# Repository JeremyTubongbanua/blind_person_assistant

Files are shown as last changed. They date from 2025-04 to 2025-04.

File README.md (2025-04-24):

# blind_person_assistant

Design and Development of Blind Person Assistant

1st place Capstone Project within the Electrical and Software Engineering program at Ontario Tech University.

## Table of Contents

- [blind_person_assistant](#blind-person-assistant)
  - [Table of Contents](#table-of-contents)
  - [Team Members](#team-members)
  - [YouTube Video](#youtube-video)
  - [Capstone Poster](#capstone-poster)
  - [Directory Overview](#directory-overview)
  - [Overall System Architecture](#overall-system-architecture)
  - [Hardware Architecture](#hardware-architecture)
    - [Headset](#headset)
    - [Exploded System Gateway](#exploded-system-gateway)
    - [Exploded Smart Cane](#exploded-smart-cane)
  - [Software Architecture](#software-architecture)
    - [Headset](#headset-1)
    - [Smart Cane](#smart-cane)

## Team Members

Group 6:

- Andy Lau - 100754380
- Emily Lai - 100825007
- Jeremy Mark Tubongbanua - 100849092
- Natasha Naorem - 100845321

Capstone Supervisor: Dr. Khalid Hafeez

## YouTube Video

3 minute video showcasing the use cases and technical features of the project.

Watch the video (https://www.youtube.com/watch?v=-XyYb4GPD1U)

## Capstone Poster

This poster was printed and displayed at the exhibition on April 4, 2025.

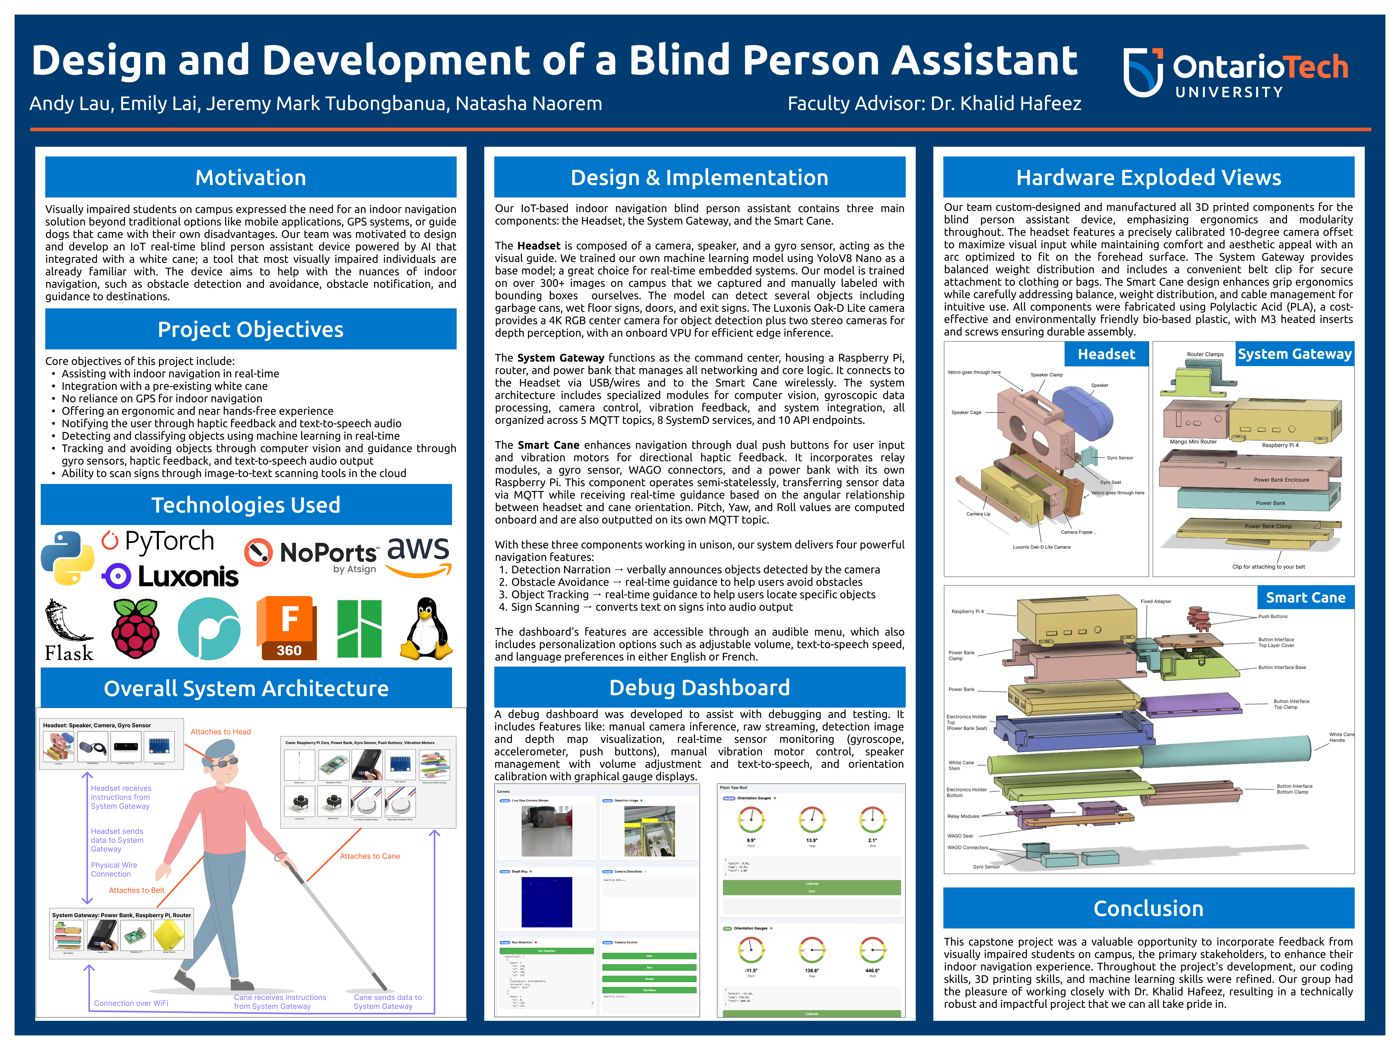
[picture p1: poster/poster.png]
Capstone Poster


Us at the exhibition:
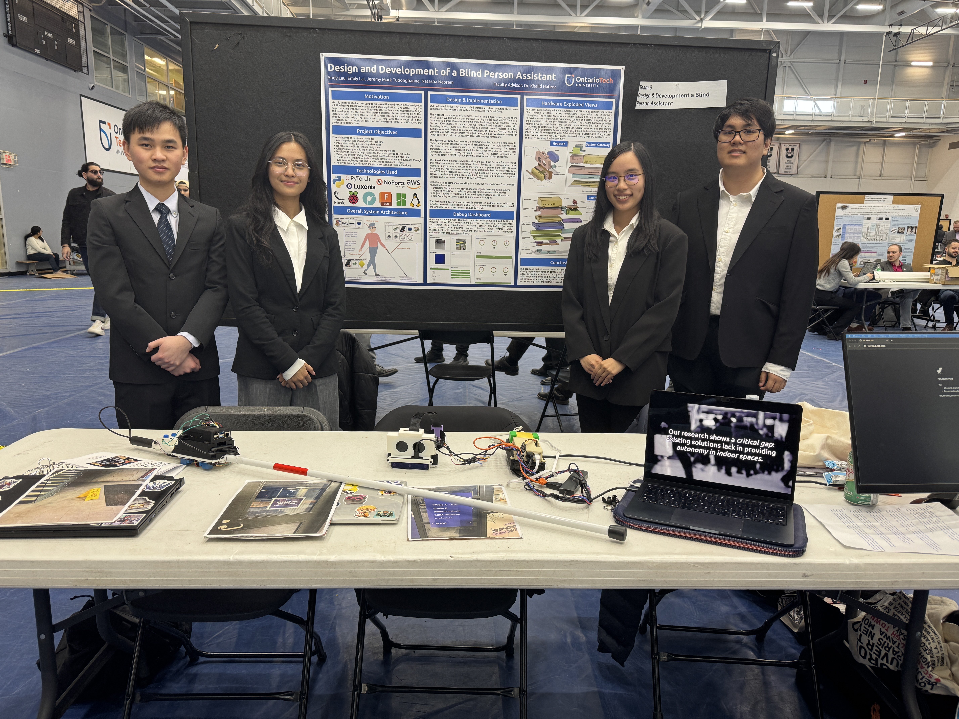
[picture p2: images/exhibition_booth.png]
Exhibition Booth


## Directory Overview

```md
blind_person_assistant/
├── model_training/ - contains YOLOv8 Nano model training code
├── headset/ - contains headset code
├── smart_cane/ - contains smart cane code
├── stls/ - contains STL files for 3D printing
├── presentations/ - contains fall and winter presentation files
├── poster/ - contains capstone poster files
├── README.md
```

## Overall System Architecture

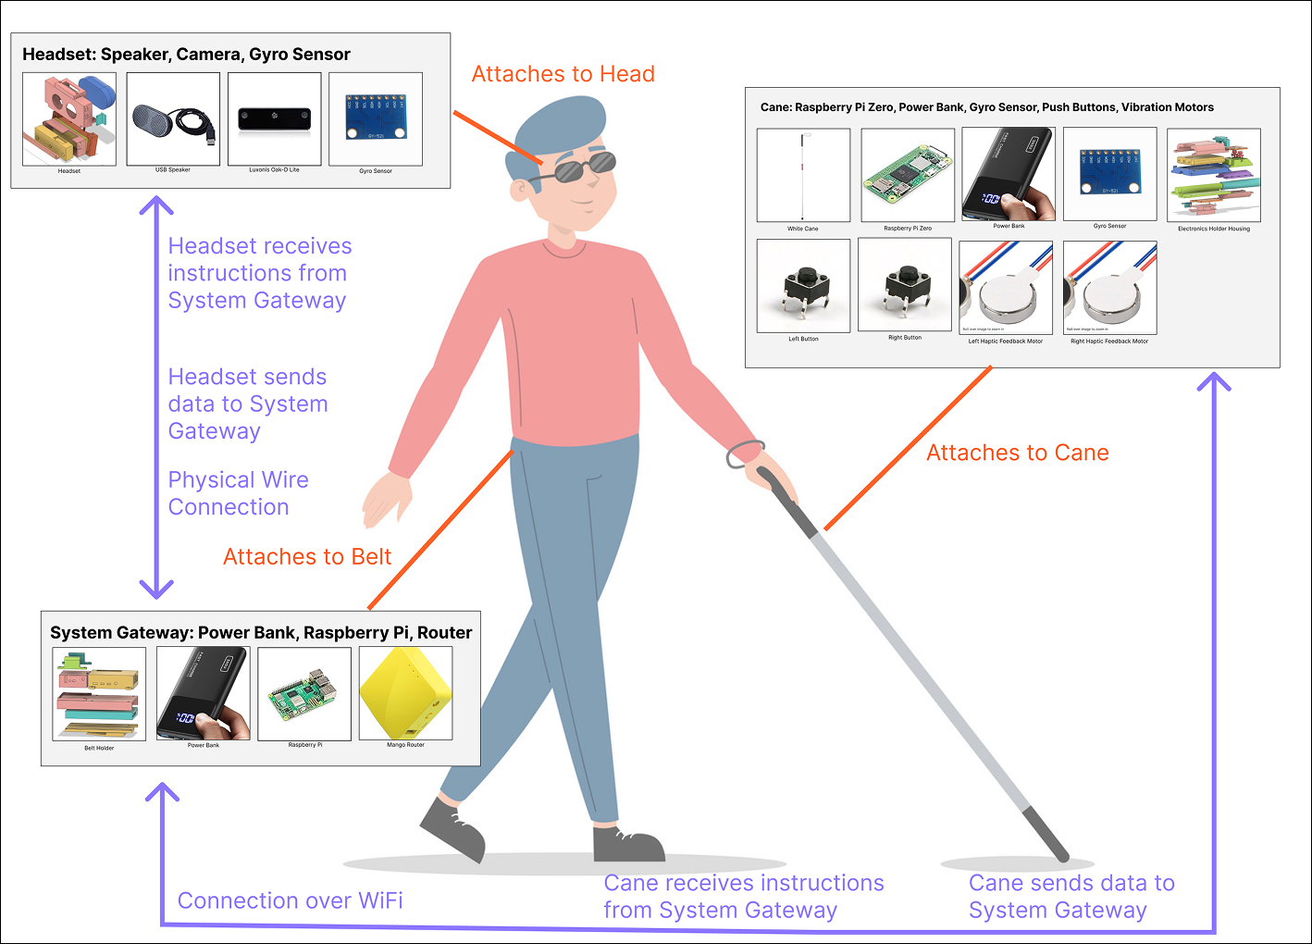
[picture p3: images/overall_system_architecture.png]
Overall System Architecture


## Hardware Architecture

We built on top of a traditional white cane (a tool that most persons who are visually impaired are familiar with) and added a few sensors to it.

### Headset

| Item | Description |
|---|---|
| Luxonis Oak-D Lite Camera | 12 MP center camera with left+right stereo cameras for depth perception |
| USB Speaker | Powered and controlled by the Pi over USB 2.0 |
| Gyro Sensor | MPU6050 |

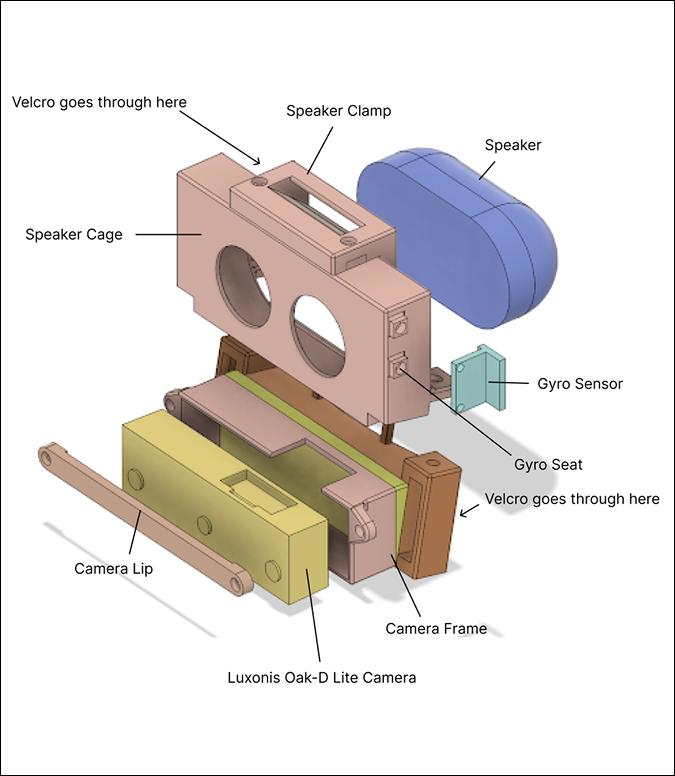
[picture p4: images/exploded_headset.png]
Exploded Headset


### Exploded System Gateway

| Item | Description |
|---|---|
| Raspberry Pi 5 | Main processing unit with 8 GB RAM, GPIO pins, and USB 3.0 ports |
| GLI Net Mango Router | Acts as access point for System Gateway Pi and Smart Cane Pi |
| Power Bank | Power delivery to the Raspberry Pi and Router |

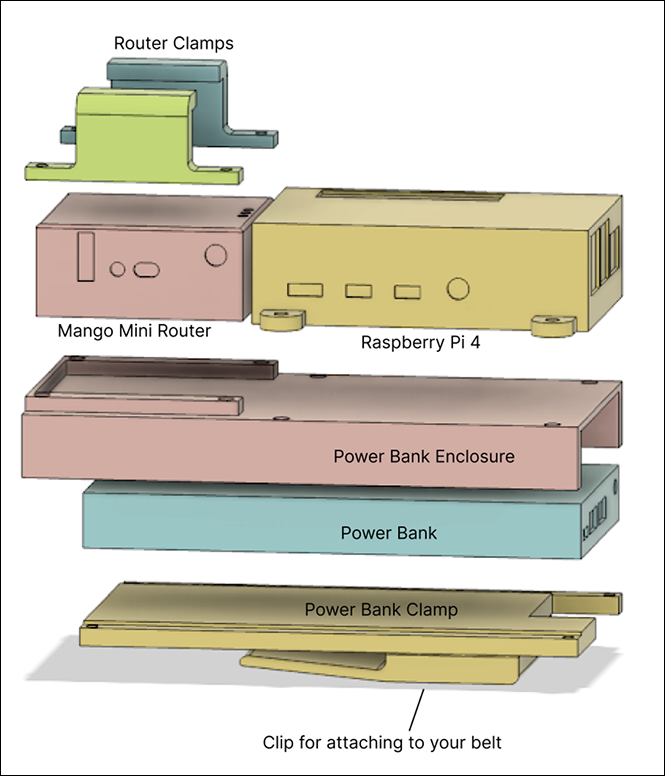
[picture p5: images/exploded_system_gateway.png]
Exploded System Gateway


### Exploded Smart Cane

| Item | Description |
|---|---|
| Raspberry Pi 4 | Main processing unit with 2 GB of RAM, GPIO pins |
| 2 Push Buttons | Connected to GND and GPIO pins |
| 2 Relay Modules | For controlling the vibration motors |
| 2 Vibration Motors | For haptic feedback |
| 2 WAGO Connectors | To act as the GND and 3.3V power rails |
| Power Bank | Power delivery to the Raspberry Pi |
| White Cane | Traditional white cane which acts as the base for the whole system |

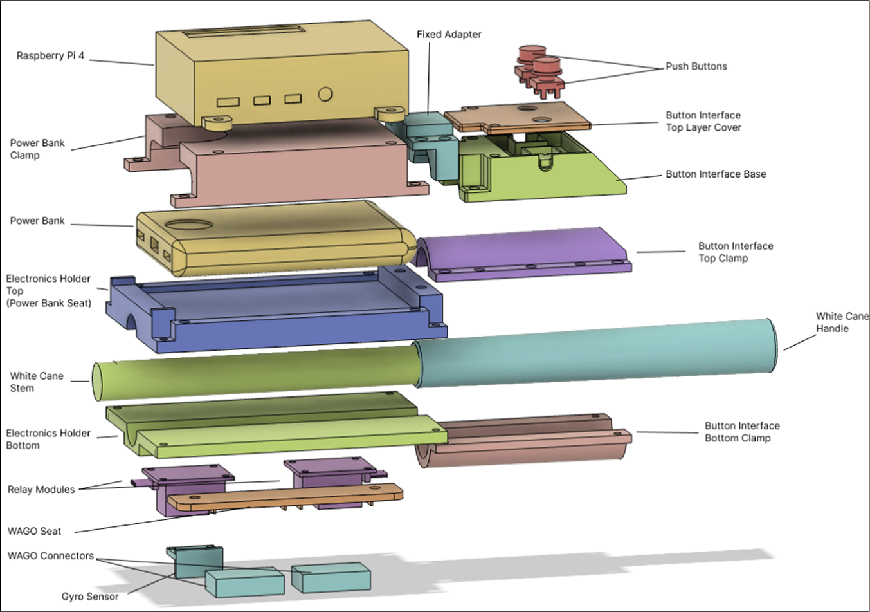
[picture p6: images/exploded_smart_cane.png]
Exploded Smart Cane


## Software Architecture

### Headset

The headset code can be found in the `headset/` directory.

| Software Module | MQTT Topic(s) | API Endpoint(s) | Description |
|---|---|---|---|
| new_camera |  1. `pi4/detections` for publishing JSON detections. 2. `pi4/depth_map` for publishing base64 depth map images for viewing purposes. 3. `pi4/detection_image` for publishing base64 detection images for viewing purposes | 1. `/video_stream` for raw live video stream. 2. `/detections` for running detections, with a comprehensive JSON reply of inference results. 3. `/` for fine tuned control of the camera | Main camera module for interfacing with the Luxonis Oak-D Lite Camera. Responsible for capturing video, calculating depth maps, running the YOLOv8 Nano model locally on the camera VPU, and outputting model inference results into MQTT topics. |
| camera_control | N/A | `/status`, `/start`, `/stop`, `/restart` | API control module for controlling the camera and getting its status. |
| speaker | N/A | 1. `/play_file` for playing preexisting audio files. 2. `/set_volume` for setting the volume of the speaker. 3. `/get_volume` for getting the volume of the speaker. 4. `/tts` for playing text-to-speech using espeak-ng lightweight TTS engine, with custom voice names, languages, and speeds. 5. `/stop` to stop audio playback. 6. `/card_info` for getting audio card information. | Audio module for interfacing with the USB speaker. Responsible for playing audio files, text-to-speech, and controlling the volume of the speaker. |
| gyro | `pi4/gyro` -> outputs raw gyro X, Y, Z, and acceleration X, Y, Z values | N/A | Stateless module for interfacing with the MPU6050 gyro sensor. Outputs raw gyro and acceleration values to the MQTT topic. |
| pitch_yaw_roll | `pi4/pitch_yaw_roll` -> outputs pitch, yaw, and roll values | 1. `/calibrate` -> runs gyro calibration sequence. 2. `/zero` zeroes the pitch, yaw, and roll values and takes the current orientation as the "zero" orientation | Stateless module for calculating the pitch, yaw, and roll of the headset using the raw gyro values. Outputs the calculated values to the MQTT topic. |
| vibration_motor_controller | `pi4/vibration_motor_controller` -> the mqtt topic that the smart cane will listen to, for vibration motor controller events sent by core | `/vibrate` -> specify left duration and right duration and the module will publish a message on controller mqtt topic. | Vibration motor controller module for controlling the vibration motors on the smart cane. Control the vibration motors using the endpoint, which publishes a message on the controller MQTT topic. |
| core | N/A | N/A | Core module for the headset. Responsible for subscribing to the MQTT topics and controlling the other modules. Runs 35 different menu options for the visually impaired user to inferace with |
| dashboard | N/A | N/A | Dashboard module for monitoring the entire system. For displaying the video stream, depth map, detection image, controlling speakers, controlling TTS engine, viewing Pitch/Yaw/Roll gauges, viewing raw sensor values and more. Mostly for exhibition purposes. |

### Smart Cane

The smart cane code can be found in the `smart_cane/` directory.

| Software Module | MQTT Topic(s) | API Endpoint(s) | Description |
|---|---|---|---|
| buttons | `pi2/button_state` | N/A | Publishes the state of the push buttons to the MQTT topic. |
| gyro | `pi2/gyro` | N/A | Stateless module for interfacing with the MPU6050 gyro sensor. Outputs raw gyro and acceleration values to the MQTT topic. |
| pitch_yaw_roll | `pi2/pitch_yaw_roll` | 1. `/calibrate` -> runs gyro calibration sequence. 2. `/zero` zeroes the pitch, yaw, and roll values and takes the current orientation as the "zero" orientation | Stateless module for calculating the pitch, yaw, and roll of the smart cane using the raw gyro values. Outputs the calculated values to the MQTT topic. |
| vibration_motors | `pi2/vibration_motor_response` | N/A | Listens to system gateway vibration motor controller, outputs response to commands on MQTT topic. Each message is paired with a uuid4. |

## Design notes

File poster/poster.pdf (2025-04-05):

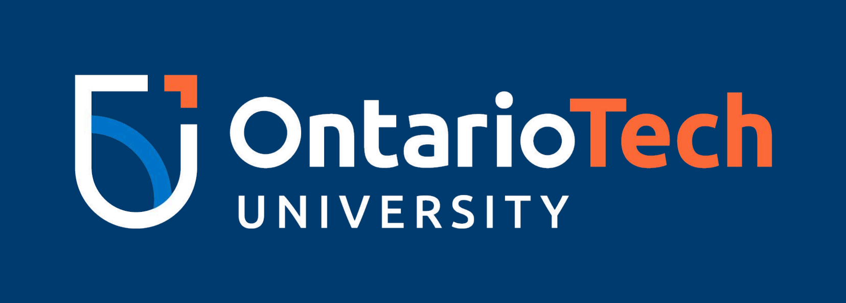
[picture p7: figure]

# Design and Development of a Blind Person Assistant

Andy Lau, Emily Lai, Jeremy Mark Tubongbanua, Natasha Naorem | Faculty Advisor: Dr. Khalid Hafeez
Motivation | Design & Implementation

# Debug Dashboard

# Project Objectives

# Hardware Exploded Views

# Conclusion

# Technologies Used

# Overall System Architecture

Visually impaired students on campus expressed the need for an indoor navigation solution beyond traditional options like mobile applications, GPS systems, or guide dogs that came with their own disadvantages. Our team was motivated to design and develop an IoT real-time blind person assistant device powered by AI that integrated with a white cane; a tool that most visually impaired individuals are already familiar with. The device aims to help with the nuances of indoor navigation, such as obstacle detection and avoidance, obstacle notification, and guidance to destinations.

Core objectives of this project includeÜ
ë Assisting with indoor navigation in real-timç
ë Integration with a pre-existing white canç
ë No reliance on GPS for indoor navigatioî
ë Offering an ergonomic and near hands-free experiencç
ë Notifying the user through haptic feedback and text-to-speech audiò
ë Detecting and classifying objects using machine learning in real-timç
ë Tracking and avoiding objects through computer vision and guidance through gyro sensors, haptic feedback, and text-to-speech audio outpu÷
ë Ability to scan signs through image-to-text scanning tools in the cloud

A debug dashboard was developed to assist with debugging and testing. It includes features like: manual camera inference, raw streaming, detection image
and | depth | map visualization, real-time | sensor | monitoring (gyroscope,
accelerometer, push buttons), manual vibration motor control, speaker management with volume adjustment and text-to-speech, and orientation calibration with graphical gauge displays.

Our IoT-based indoor navigation blind person assistant contains three main components: the Headset, the System Gateway, and the Smart Cane.

The Headset is composed of a camera, speaker, and a gyro sensor, acting as the visual guide. We trained our own machine learning model using YoloV8 Nano as a base model; a great choice for real-time embedded systems. Our model is trained on over 300+ images on campus that we captured and manually labeled with bounding boxes ourselves. The model can detect several objects including garbage cans, wet floor signs, doors, and exit signs. The Luxonis Oak-D Lite camera provides a 4K RGB center camera for object detection plus two stereo cameras for depth perception, with an onboard VPU for efficient edge inference.

The System Gateway functions as the command center, housing a Raspberry Pi, router, and power bank that manages all networking and core logic. It connects to the Headset via USB/wires and to the Smart Cane wirelessly. The system architecture includes specialized modules for computer vision, gyroscopic data processing, camera control, vibration feedback, and system integration, all organized across 5 MQTT topics, 8 SystemD services, and 10 API endpoints.

The Smart Cane enhances navigation through dual push buttons for user input and vibration motors for directional haptic feedback. It incorporates relay modules, a gyro sensor, WAGO connectors, and a power bank with its own Raspberry Pi. This component operates semi-statelessly, transferring sensor data via MQTT while receiving real-time guidance based on the angular relationship between headset and cane orientation. Pitch, Yaw, and Roll values are computed onboard and are also outputted on its own MQTT topic.

With these three components working in unison, our system delivers four powerful navigation featuresÜ
&S Detection Narration → verbally announces objects detected by the camerk
%S Obstacle Avoidance → real-time guidance to help users avoid obstacle@
KS Object Tracking → real-time guidance to help users locate specific object@
5S Sign Scanning → converts text on signs into audio output

The dashboard s features are accessible through an audible menu, which also includes personalization options such as adjustable volume, text-to-speech speed, and language preferences in either English or French.

Our team custom-designed and manufactured all 3D printed components for the blind person assistant device, emphasizing ergonomics and modularity throughout. The headset features a precisely calibrated 10-degree camera offset to maximize visual input while maintaining comfort and aesthetic appeal with an arc optimized to fit on the forehead surface. The System Gateway provides balanced weight distribution and includes a convenient belt clip for secure attachment to clothing or bags. The Smart Cane design enhances grip ergonomics while carefully addressing balance, weight distribution, and cable management for intuitive use. All components were fabricated using Polylactic Acid (PLA), a cost-effective and environmentally friendly bio-based plastic, with M3 heated inserts and screws ensuring durable assembly.

This capstone project was a valuable opportunity to incorporate feedback from visually impaired students on campus, the primary stakeholders, to enhance their indoor navigation experience. Throughout the project s development, our coding skills, 3D printing skills, and machine learning skills were refined. Our group had the pleasure of working closely with Dr. Khalid Hafeez, resulting in a technically robust and impactful project that we can all take pride in.

## Smart Cane

Headset | System Gateway

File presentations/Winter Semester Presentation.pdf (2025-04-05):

# Design and Development of a Blind Person Assistant

TEAM 6
Andy Lau
Emily Lai
Jeremy Mark Tubongbanua
Natasha Naorem

Advisor: Dr. Khalid Hafeez

1

# The Problem & Research

N

# The Problem

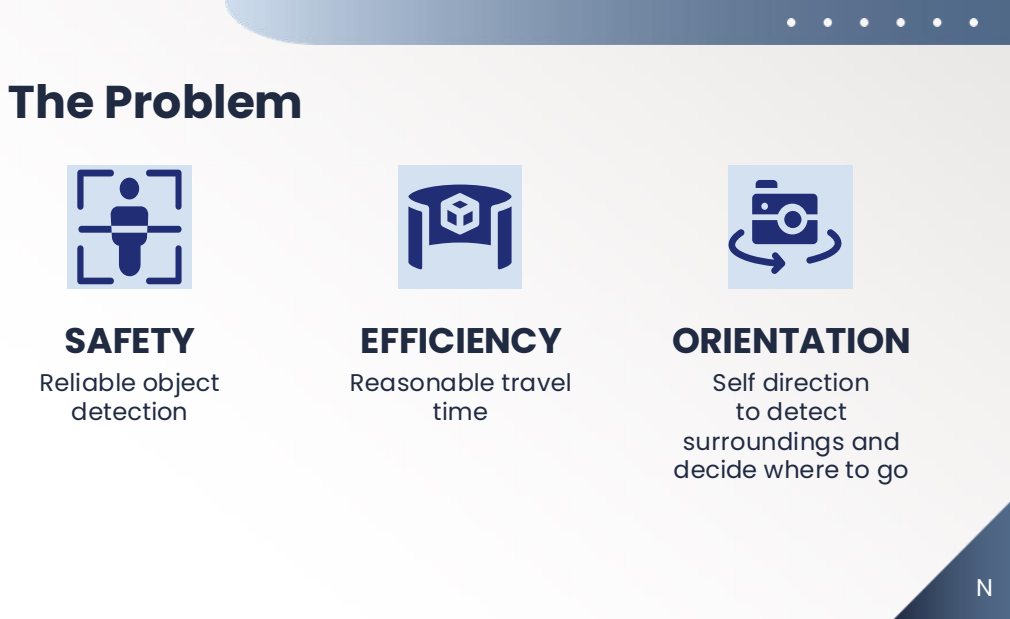
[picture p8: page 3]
SAFETY; EFFICIENCY; Reliable object detection; Reasonable travel time

ORIENTATION
Self direction
to detect
surroundings and
decide where to go

# How well do available navigation tools meet your needs?

## SURVEY QUESTION:

Compared to outdoor solutions,

# there is a gap in the market for development of suitable indoor

orientation/navigation systems.

## SURVEY CONCLUSION:

# Current indoor navigation systems do not focus on human-centered design for

visually impaired users.

## PROBLEM STATEMENT:

# Sighted Guide

# LIMITATION: Availability

N

# Current Solutions for Independent Navigation

# OBSTACLE AVOIDANCE

### Traditional Aids - White Cane - Guide Dog

### Mobile Applications - Google Maps - Lazarillo - Voice Vista

# ORIENTATION & NAVIGATION

# Stakeholder

# Discussion: Low Vision Student on Campus

### Limitation: Disruptive Navigation Simultaneous use of a white cane and mobile phone

N

# Non-Disruptive Navigation

# PROJECT OBJECTIVES

### - Increase detection range - Detect overhanging obstacles - Support the white cane

### - Reduce reliance on simultaneous use of navigation tools - Improve navigation efficiency

# Improved Obstacle Avoidance

N

2

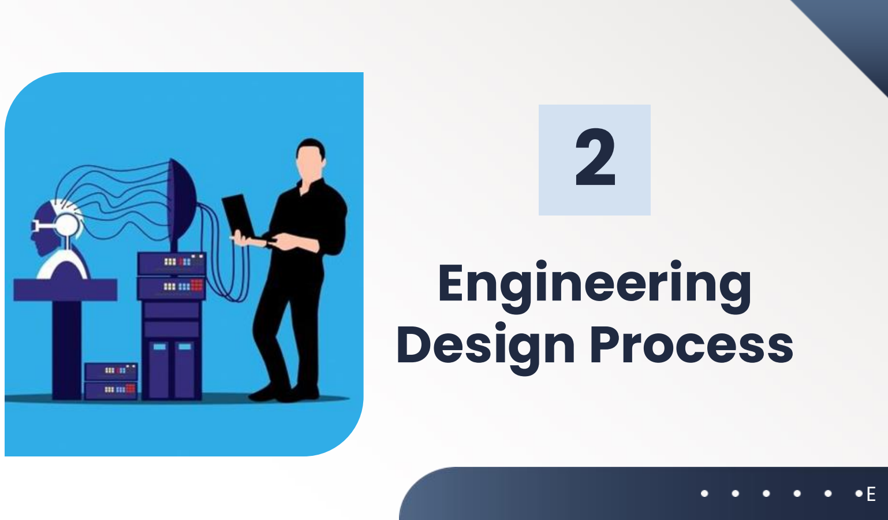
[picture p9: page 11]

# Engineering Design Process

E

# Design Requirements

When establishing a design, we wanted to meet certain requirements:

GPS is not reliant enough indoors to be used to a certain extent.

The system would need to use multiple sensors and have some way of guiding the user indoors. It would need to conduct edge computing for real-time assistance.

If we were to build an app, it can be a hassle to hold both a phone and a white cane. We want to offer a hands-free experience so that the user’s free hand can be used for better things

## Keep the White Cane

## Assist with Indoor

## Navigation in Real-Time

## Do Not Rely on a GPS

## Hands-Free Experience

Blind individuals rely heavily on their white cane, we do not want to remove or replace this crucial component.

E

# Use Cases

Detect objects in real-time, and notify the user
through TTS (text-to-speech). The user can opt
in for active detection or detection as needed.

Guide the user to an
object that was detected
and classified. The system will use sensors and
actuators to play a game
of “hot and cold” and
guide the user to a
desired object.

Many signs and poster
boards are not visually
impaired accessible. A
text scanner would help
with narrating texts, like large signs, using AWS
Textract and TTS (text-to-speech).

## Obstacle Detection &

Classification | Object Tracking | Text Scanning

Our three key features that we offer to a visually impaired user assisting with indoor navigation.

# Design Iteration 1

Smart Cane with Omni Wheel at the
Tip● | Wheel component for ease of
| cane movement
- Sensor increases range of area
| that can be sensed
Challenges ● | Wheel changes the fundamental
| white cane design
- Moving sensor may be difficult to
| track

E

# Design Iteration 2

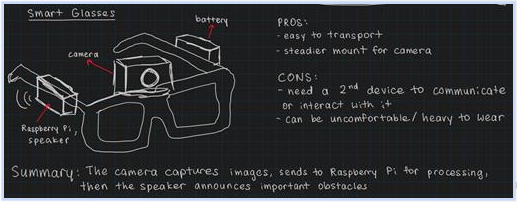
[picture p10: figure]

Smart Glasses with Camera ● | Camera captures images and
| sends to Raspberry Pi for processing
- Speaker announces important
| obstacles
Challenges ● | Poor user experience due to
| imbalanced and heavy weight on the head

E

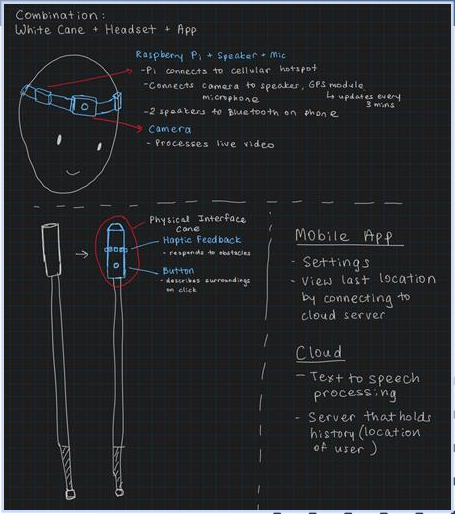
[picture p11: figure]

# Design Iteration 3

Smart Cane with Headset ● | Headset ○ | Raspberry Pi, speaker,
| | microphone, camera
- Can find obstacles and
| | report audibly to the user
- | Cane ○ | Haptic feedback for
| | obstacles
- Button for user input
- | Mobile App ○ | For settings modification

E

# The Design We

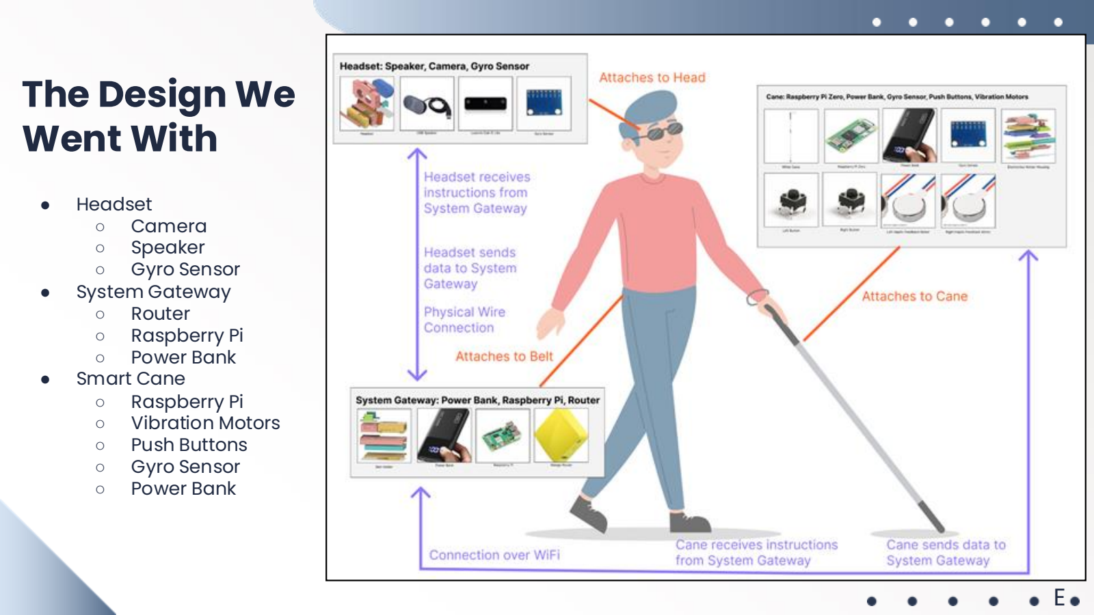
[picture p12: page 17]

Went With ● | Headset ○ | Camera ○ | Speaker ○ | Gyro Sensor ● | System Gateway ○ | Router ○ | Raspberry Pi ○ | Power Bank ● | Smart Cane ○ | Raspberry Pi ○ | Vibration Motors ○ | Push Buttons ○ | Gyro Sensor ○ | Power Bank

E

# Luxonis Oak

# -D Lite

The core piece of hardware for our capstone.
Has 3 Cameras:
1. Center

4K (12MP) RGB Camera
2. Left shutter stereo camera
3. Right shutter stereo camera Has an internal VPU (Visual Processing Unit). Edge Processing
Is Powered by USB

-C and can
transmit data through the same cable. Coding in Python and lots of documentation

E

# Depth Perception

Using the Left and Right Stereo Cameras
Mimics human binocular vision to estimate depth VPU generates a depth map
Oak-D lite comes with limitation perception range of [0.4m, 8m]

E

# Headset

Iteration 1 ● | Had a Horizontal Velcro Strap ● | Had a Camera Enclosure & Lip
Improvements Needed: ● | Needs to hold speaker ● | Needs to hold a Gyro sensor ● | USB cable is obstructive ● | Needs a vertical strap hole for

better stability on the head

J

# Headset Iteration 1.5

Never became a full iteration, but we played around with different ideas. We had trouble figuring out where to put the speaker.

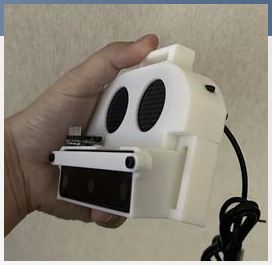
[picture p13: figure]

# Headset Iteration 2

New Features: ● | New Gyro Seat ● | New Snap-Fit Speaker Enclosure ● | Camera was flipped upside

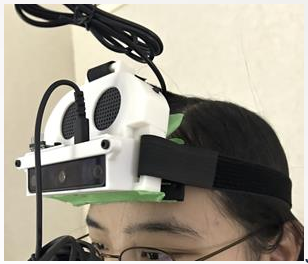
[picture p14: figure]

down to help with wire routing (which originally blocked the user’s eyes)
- Has a vertical strap hole

# Headset Iteration 3 (Final)

New Features: ● | Shifted Speaker Forward ● | More Comfortable ● | Angled Camera (more info in

next slides)

# Headset Physical Subcomponents

Put together using M3 heated inserts and M3 screws
1. Camera Frame
2. Camera Lip
3. Speaker Cage
4. Speaker Clamp
5. Gyro Seat

# Subcomponent 1:

Camera Frame ● Back of the enclosure is curved to fit

most foreheads
- Has 2 rectangular holes for a velcro strap
- Slim

-fit the Luxonis Oak

-D Lite with 0.1
mm tolerance

# Subcomponent 1: Camera Frame

Having an angled camera frame optimizes the camera view.

# Subcomponent 2: Camera Lip

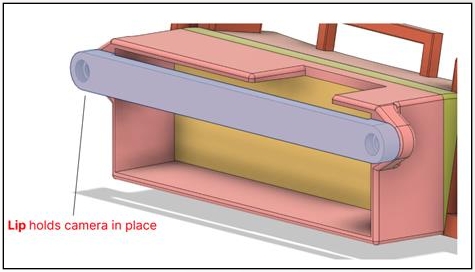
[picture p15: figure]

Lip holds the camera in place and prevents it from falling out of the enclosure, without blocking the 3 cameras.
Uses ● | 2 M3 heated inserts (on the frame) ● | 2 M3x3” screws to hold lip in place

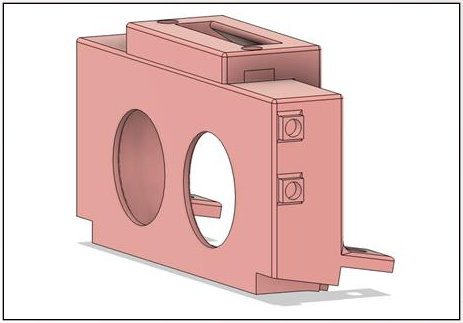
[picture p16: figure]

# Subcomponent 3: Speaker Cage

USB Speaker is snap

-fitted into the Speaker
Cage
Speaker Cage is screwed onto the Frame using M3 heated inserts and M3 screws.

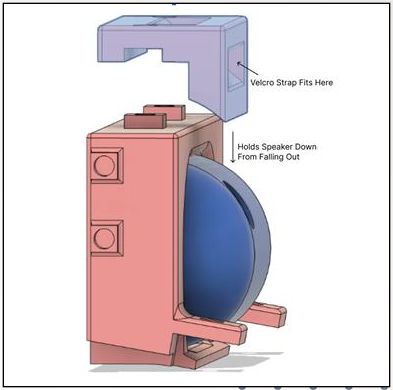
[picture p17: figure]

# Subcomponent

4:

# Speaker Clamp

Two features
1. Has a rectangular hole for a vertical velcro strap that runs on top of the head
2. Holds the speaker down from falling out of the snap

-fitted cage
Speaker clamp is held down by 2 M3 heated inserts and 2 M3 screws

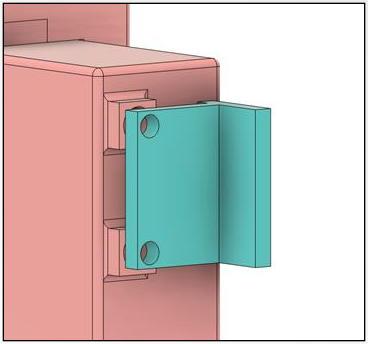
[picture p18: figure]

# Subcomponent 5: Gyro Seat

Additionally, two heated inserts are added to the Speaker Cage
The Gyro Sensor for the headset is screwed down to the Speaker Cage on its side.

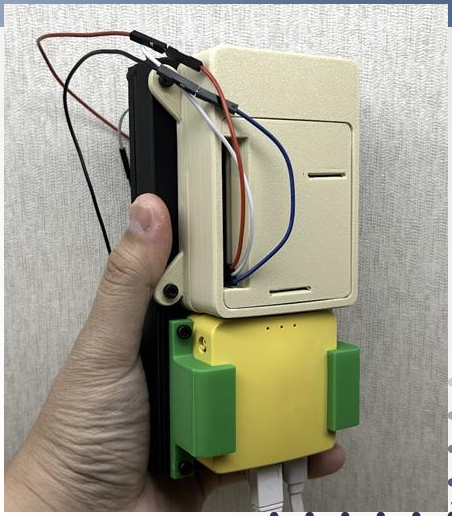
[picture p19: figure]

# System Gateway

Is physically connected to the
Headset’s components (Camera, Gyro Sensor, and USB Speaker)
Communicates with the Smart Cane Runs the core business logic and makes critical decisions
Consists of: ● | Raspberry Pi ● | Router ● | Power Bank

# System Gateway:

# Exploded View

Most items are either clamped or screwed using M3 heated inserts, screws, and nuts.
A belt clip is there in case you want to put it on your belt.

# System Gateway

# Subcomponents

Design Subcomponents:
1. Mango Router Clamps
2. Power Bank Enclosure
3. Power Bank Clamp

# System Gateway Design Subcomponent 1

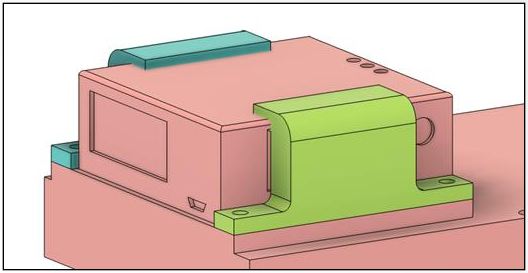
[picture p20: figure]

Holds the Router down in place
Ensures no important ports are blocked

# System Gateway Design Subcomponent 2

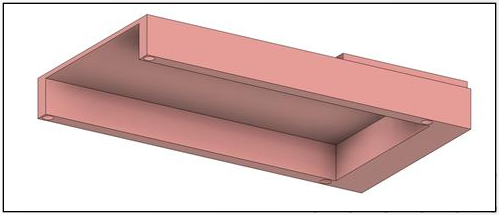
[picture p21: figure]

Power Bank Enclosure holds the power bank, with tolerance 0.1mm
Has heated inserts for various other parts to attach themselves to.

# System Gateway Design Subcomponent 3

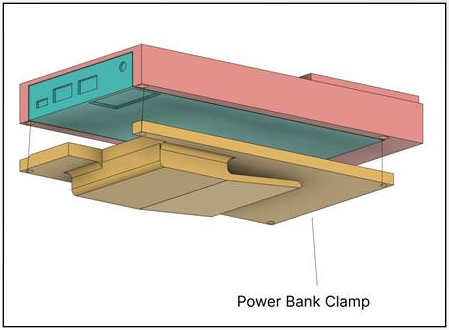
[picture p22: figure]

The Power Bank Clamp clamps the power bank to the enclosure, and offers a clip so it can be tucked away nicely on a pants, belt, or bag.

# Smart Cane

Utilizes a standard White Cane as its base.
Acts as an interface for the user to interact with the system
Contains ● | Raspberry Pi ● | Push Buttons ● | Gyro Sensor ● | Relay Modules ● | Vibration Motors ● | WAGO Terminal Connectors (5V

and GND)

# Smart Cane Iteration 1

Goods: ● | Had a Gyro Seat ● | Had a Raspberry Pi Zero holder ● | Had a Power Bank Clamp
Bad● | No Button Interface ● | Would Spin with the Cane

# Smart Cane Iteration 2

Improvements Made: ● | Added a Button Interface ● | Power Bank Clamp Hole was added so that

you can view the battery %
- The Electronics Holder component is attached to the button interface, which is fixed, so now they are both fixed and will not spin.
Future Improvements: ● | | Needs a regular Raspberry Pi to use I 2C with Gyro Sensor
- A place for Relay Modules to control the
| | Vibration Motors

# Smart Cane Iteration 3 (Final)

New Features:
- Added Relay Modules
- Added WAGO Connectors to act as terminals for 5V and GND
- Added a Raspberry Pi 4 mount on top of Power Bank Clamp

# Smart Cane Iteration 3 (Final) 360 Video

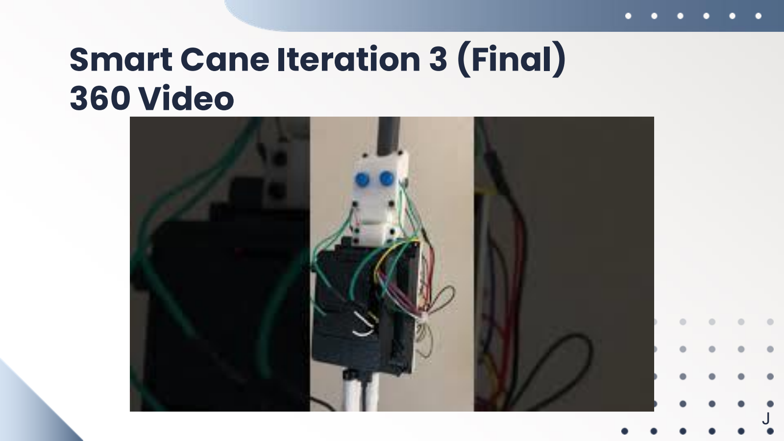
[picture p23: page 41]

Smart Cane (http://www.youtube.com/watch?v=6u8WdEg2CwE)

# Smart Cane Exploded View

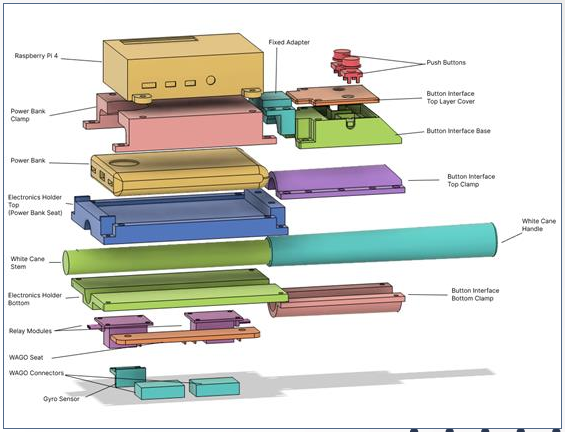
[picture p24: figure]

Parts are held together with M3 heated inserts, nuts, and screws.
3 Design Subcomponents:
1. Button Interface
2. Adapter
3. Electronics Holder

# Smart Cane Design Subcomponent 1

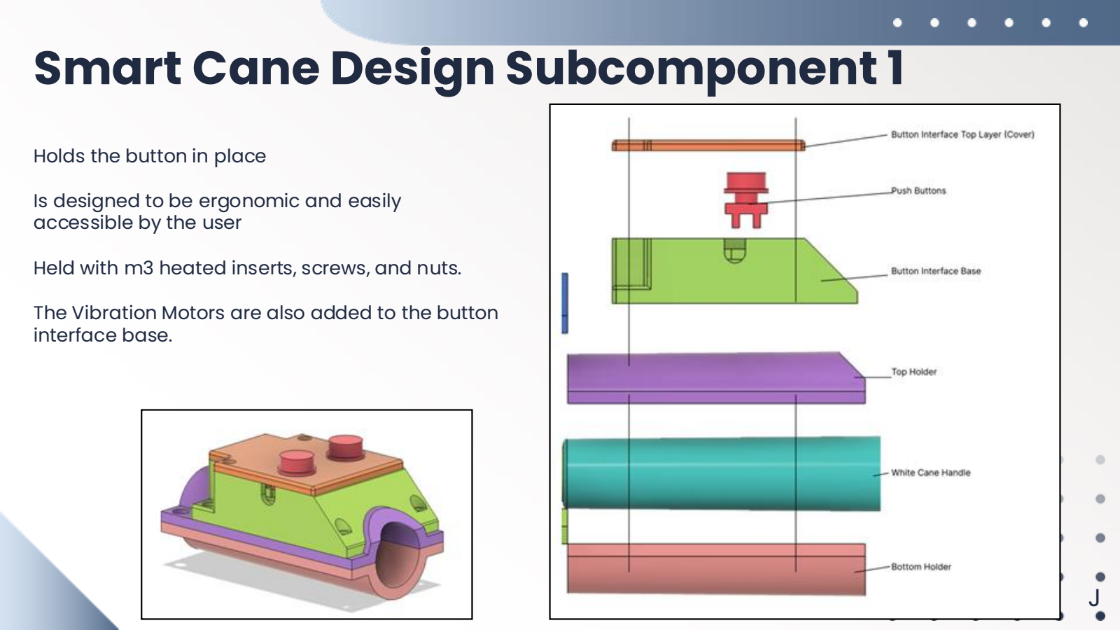
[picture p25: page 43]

Holds the button in place
Is designed to be ergonomic and easily accessible by the user
Held with m3 heated inserts, screws, and nuts. The Vibration Motors are also added to the button interface base.

# Smart Cane Design Subcomponent 2

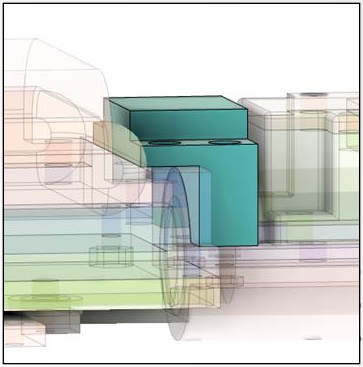
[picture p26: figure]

The adapter connects the two major subcomponents together:
1. The button interface (previous slide)
2. The electronics holder (next slide)
It ensures that the electronics holder is in a fixed position and does not spin along the white cane axis.

# Smart Cane Design Subcomponent 3

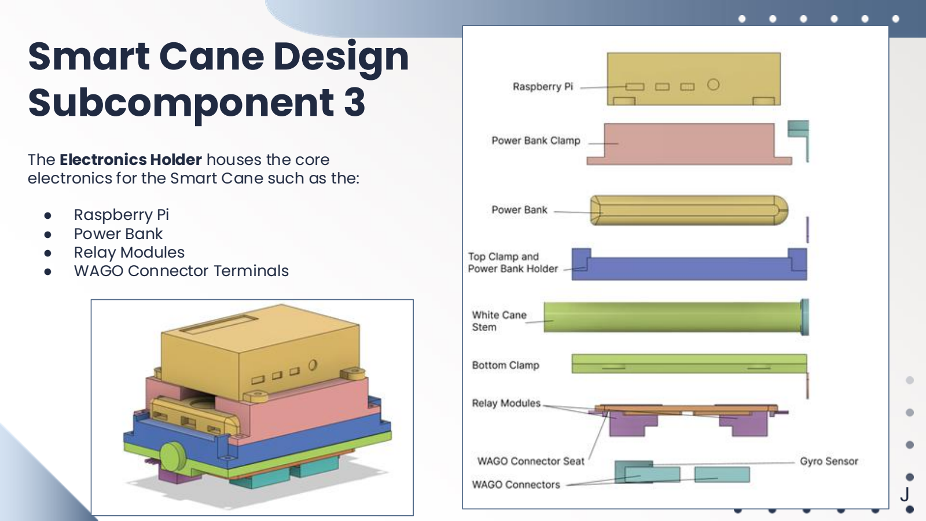
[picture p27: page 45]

The Electronics Holder houses the core electronics for the Smart Cane such as the:
- Raspberry Pi
- Power Bank
- Relay Modules
- WAGO Connector Terminals

# Smart Cane Full Assembly Screenshot 1

# Smart Cane Full Assembly Screenshot 2

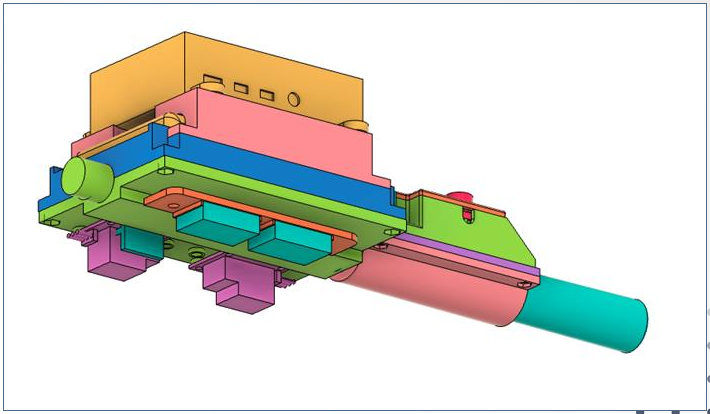
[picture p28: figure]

# Software Modules

Model Training
A jupyter notebook for training the model and converting it into a format compatible with the Luxonis Oak-D Lite

System Gateway Raspberry
Pi
Contains core business logic with critical decision making Receives Object Detections and Classifications from
Camera
Generates Depth Map
Runs daemon speaker service Contains lightweight TTS
engine
Contains daemon vibration
motor controller service
Computes Pitch, Yaw, and Roll of Headset Orientation

Smart Cane Raspberry Pi
A semi-stateless system that does two things:
1. Forwards events to the
System Gateway Pi
2. Listens for events sent from the System
Gateway Pi
Computes Pitch, Yaw, and Roll of Smart Cane Orientation

# Model Training

Collected 214 images of poles, garbage cans, doors, exit signs, general signs, wet floor signs Manually drew bounding boxes on training images
Trained using YOLOv8n as the base model
Converted to `.blob` format which is compatible with Luxonis Oak-D Lite VPU Edge Processing

E

# Model Inference Samples

Early iteration of model

E

# Model Inference Samples

Final iteration of model

E

# UA Walkthrough

capstone fall 2024 (http://www.youtube.com/watch?v=4lL-887s8Vo)

E

# System Gateway Raspberry Pi

## 8 Processes running on SystemD services

1. Camera → runs pipelines to camera, receives detections and depth map, outputs detections on MQTT

### 2. Speaker → manages volume, plays M4A files, hosts a lightweight TTS engine 3. Gyro → reads Gyro values from I2C bus and publishes on MQTT topic

4. Pitch-Yaw-Roll → computes Pitch, Yaw, and Roll from Gyro values with Gyro sensor orientation in consideration

### 5. Core → communicates with cane, runs menu options, makes critical decisions 6. Camera Controller → exposes HTTP interface to stop, start, restart, and run inference

7. Vibration Motor Controller → exposes HTTP interface to run left or right vibration motor on Smart Cane

### 8. Dashboard → exposes a HTML/CSS debug dashboard

# Smart Cane Raspberry Pi

## 4 Processes running on SystemD services

### 1. Buttons → listens for button events and publishes on MQTT topic 2. Gyro → reads Gyro values from I2C bus and publishes on MQTT topic 3. Pitch-Yaw-Roll → computes Pitch, Yaw, and Roll from gyro values and publishes to MQTT

4. Vibration Motors → listens on System Gateway MQTT and actuators vibration motors if instructed to do so.

# Debug Dashboard

15 different controls
19 different panels to view system status from Mainly used as a debug dashboard.
Contains: Gyro gauges, depth map, live video feed, speaker controls, camera controls, and manual TTS.

# Debug Dashboard

Camera Controls
- View Live Raw Camera Stream
- View the Detection Image (when detection is ran)
- View Depth Map (when detection is ran)
- View list of detections in JSON format
- Run the Detection with a button through HTTP interface
- Start, Stop, Restart the Camera or Get Camera Status

# Debug Dashboard

# Debug Dashboard

Gyro Controls ● | | | | | | Headset Raw Gyro Values (Gyro X, Y, Z,
| | | | | | Acceleration X, Y, Z)
- Smart Cane Raw Gyro Values (Gyro X, Y, Z,
| | | | | | Acceleration X, Y, Z)
- | Headset Pitch, Yaw, Roll Gauges ● | Smart Cane Pitch, Yaw, Roll, Gauges ● | Headset Calibrate Pitch, Yaw, Roll ● | Smart Cane Calibrate Pitch, Yaw, Rol, ● | Headset Zero Yaw ● | Smart Cane Zero Yaw

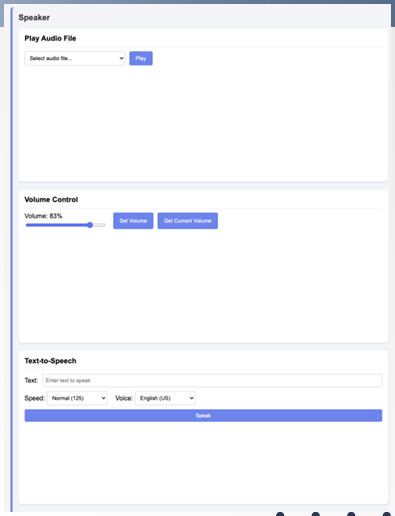
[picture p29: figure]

# Debug Dashboard

Speaker Controls
- Play a pre-downloaded audio file (like a Notification Sound)
- Set Volume (Slider)
- Get Volume
- Enter Text for the TTS Engine to Narrate
- Select Speed
- Select Voice Language/Accent

# Debug Dashboard

Button State
- View the button state MQTT topic live from the Smart Cane
- Used primarily by `core` to make effective decisions

# Debug Dashboard

Button State
- View the button state MQTT topic live from the Smart Cane
- Used primarily by `core` to make effective decisions

# Debug Dashboard

Vibration Motor Controller ● | Vibrate Motors ○ | Left for X Seconds ○ | Right for X Seconds ○ | Sends HTTP Request to Controller ● | Controller publishes a message on their

MQTT Topic on Headset Pi
- Smart Cane is listening to MQTT Topic and sends an ACK response
- Smart Cane actuates Vibration Motors through Relay Modules

# Use Case 1: Obstacle Detection & Classification

1. Camera Detects Objects
2. Speaker Service Narrates The Detections and their Distances

# Use Case 2: Object Tracking

1. Camera Detects Objects
2. Speaker Service Narrates The Detections and their Distances
3. User Chooses Which To Track
4. Gyro Sensors Calculate Angle Offset
5. Left/Right Vibration Motors Guide The User To Object

# Use Case 3: Text Scanning

1. Camera Detects a Sign
2. User Walks Up To a Sign
3. User Activates Text Scanning
4. AWS Textract is used to scan sign
5. Speaker TTS Narrates Text

3

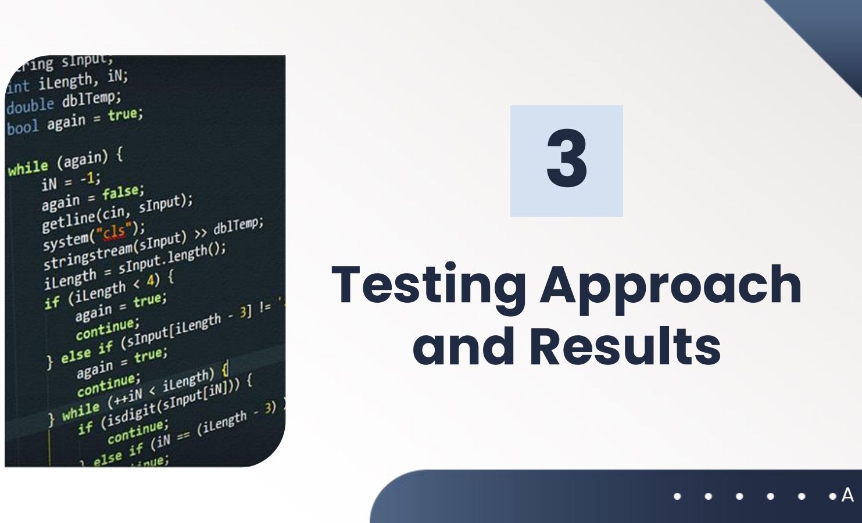
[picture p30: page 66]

# Testing Approach and Results

A

## OUR

## CRITERIA

# Testing Approach

Expectations of our tests were based on research for stakeholders and on professor’s suggestions

Our aim was to test components individually and when they were integrated together. OUR AIM

## Hardware

Hardware Components: Luxonis Oak-D Lite, Mango Router, Power Bank, Raspberry Pi 5 8 GB, Raspberry Pi 4 2 GB, USB Speaker, Push Buttons, Relay Module, Vibration Motors, Gyro Sensor
A

# Acceptance Testing Process

What We tested for:
We tested for usability, operation duration, and properly working features
Procedure
A different methodology is used for each kind of test
Manual tests are conducted when doing functional tests and results are observed by the tester
Usability tests are completed in a controlled environment, where the settings are in an indoor environment
Performance testing is tested using a testing script

# Acceptance Testing Criteria

Stakeholder Testing: The product is tested against stakeholder requirements to confirm that it meets user expectations and fulfills the intended purpose.
Functional Testing: Each system component is verified against functional specifications, ensuring that all features, workflows, and business processes operate correctly. This includes validating data processing, calculations, and system integrations.
Usability Testing: Real users interact with the system to assess its intuitiveness, accessibility, and ease of use. Feedback is gathered on learnability and user satisfaction.
Compatibility Testing: The system is tested across different browsers, operating systems, devices, and network configurations to ensure consistent performance in all intended environments. Performance Testing: The system’s responsiveness, stability, and resource utilization are evaluated under various conditions, including normal usage, peak loads, and stress scenarios. This ensures it meets performance benchmarks for speed, scalability, and reliability.

# User Scenario

User Scenarios | Related Tests
A visually impaired user is navigating through the interior of Durham College, where a support pillar is located in the center of one of the pathways. As they approach a pole, the system detects it and provides a visual bounding box with a distance estimate. | S-1
A visually impaired user is navigating through the interior of Durham College, where a support pillar is located in the center of one of the pathways. As they approach a pole, the system detects it and announces the object detected, in this case, a pole, and the distance through the headset speaker. They are also able to gauge the direction through the haptic feedback on the cane. | S-2, S-3
A system administrator opens the GUI to monitor the Smart Assistant's performance, viewing live object recognition and adjusting settings as needed. | S-4

# Stakeholder Testing

Test Case # | Test Name
S-1 | Object Recognition and Object Distance Estimation
S-2 | Text to speech functionality and speaker functionality
S-3 | Gyro Sensor Connections
S-4 | GUI for the system

These tests validate whether the system’s features function correctly in practical scenarios, and meet real word expectations of users/stakeholders

# Functional Testing

### 15 Test Cases

Functional testing ensures that each component of the Smart Assistant system operates according to the defined functional specifications. Verifies that all features, workflows, and integrations behave as expected. Most are to test software execution

Test Case # | Test Name | Description | Preconditions | Postconditions
A-1 | Announce Detections | Read detections that are inferred from the camera and use the speaker service’s Text To Speech capabilities to narrate the detections to the user | Camera is on. Objects detected. Speaker service fully functional | Detections are narrated to the user

# Usability Testing

Usability testing evaluates how intuitive and user-friendly the Smart Assistant system is for its intended audience. This process assesses ease of navigation, accessibility, and overall user experience by observing real users interacting with the interface.
Test Case # | Test Name | Description | Preconditions | Postconditions
B-1 | White Cane Button Controls Said on Speaker | Whenever a button is pressed on the white cane, the speaker will speak out what option that button does | All components of the white cane assistant are turned on | Text-to-speech command is issued to speaker
B-2 | Cane is still usable | The system is usable and intractable without the need for vision | Have the cane components physically on the cane | Able to use the cane as normal
B-3 | System is usable without vision | The system should be usable by the blind and visually impaired | Be able to interface with the system with your eyes closed | Be able to use the system

# Compatibility Testing

Make sure program is compatible with pre-existing hardware or software

Test Case # | Test Name | Description | Preconditions | Postconditions
C-1 | Dashboard on different web browsers. | Test that the debug dashboard works on different web browsers | Dashboard is operational | Dashboard is responsive and functional

# Performance Testing

Tests on if the blind person assistant system has acceptable reliability, speed, and responsiveness.

### 8 Tests

Most Tests are tested using the Test.sh script
By testing, we found the limitations of the of running the AI assistant program for too long.
Test Case # | Test Name | Description | Preconditions | Postconditions
D-1 | Headset Battery Life (Idle) | Tests the battery life capabilities under idle load | All systems and components are powered and functional in the headset, but no continuous usage. Battery is charged at 100% before test

Battery operates as
long as possible

# Test.sh


- Testing script that checks the execution time of commands
- Computes the execution time in seconds
- Ran by using connected debug laptop
- All responses are recorded in a second

## Test.S

A

# Test Results

All of all test are found to be successful Example successful cases:

Stakeholde r Test Case # | Date Test Performed | Test Owner | Result: Pass/Fail | Comments
S-1 | Object Recognition and Object Distance Estimation | Dr. Khalid Abdel Hafeez | Pass | Maybe try to make it recognize corners
Functional Test Case # | Date Test Performed | Test Owner | Result: Pass/Fail | Comments
A-1 | March 5, 2025 | Jeremy Mark Tubongbanua | Pass | Detections that are outputted by the camera stream service can be successfully narrated by the speaker using the Text To Speech engine in real-time.

# Test Results

Usability Test Case # | Date Test Performed | Test Owner | Result: Pass/Fail | Comments
B-1 | March 13, 2025 | Andy Lau | Pass | No comments
B-2 | March 13, 2025 | Jeremy Mark Tubongbanua | Pass | Typically, the visually impaired are already comfortable with a cane, so it is already integrated with a tool they are familiar with.
B-3 | March 13, 2025 | Jeremy Mark Tubongbanua | Pass | Menu navigation is functional fully with the buttons, and do not have to use your eyes in order to interact with the system

# Test Results

Compatibility
Test Case #

Date Test
Performed

Test Owner Result:
Pass/Fail

Comments

C-1 | March 13, 2025 | Jeremy Mark Tubongbanua and Emily Lai
Pass | Dashboard is
responsive
and functional
on Google
Chrome,
Safari, Firefox,
and also on
mobile
phones.

# Test Results

Performance Test Case # | Date Test Performed | Test Owner | Result: Pass/Fail | Comments
D-1 | March 13, 2025 | Jeremy Mark Tubongbanua | Pass | ~10 hour long battery life
D-2 | March 13, 2025 | Jeremy Mark Tubongbanua | Pass | ~6 hour long battery life
D-3 | March 13, 2025 | Emily Lai | Pass | ~12 hour long battery life

# Issues and Defects

Defect# | Action Item(s) | Improvement(s)
1 | During test A-1, the camera was overheating. | Improvement was implemented such that camera inference can be controlled on demand. Continuous camera inference was causing the camera to overheat, so this method was opted out of.
2 | Improper Camera Inference was common during test A-1. | Increasing the confidence threshold to 80% caused improper inferences to be less frequent.
3 | Objects weren’t being detected during test A-1. | Since the threshold was too high, the confidence threshold of the machine learning model was reduced to 60%.
4 | Vibration Motors burnt out during test D-5 | Due to an electrical issue, the vibration motors were burnt out and had to be replaced. To ensure this did not happen again, we ensured wires avoided touching each other using electrical tape.

# Budget

Total budget: $1,062.12

# Thank You

Any Questions?

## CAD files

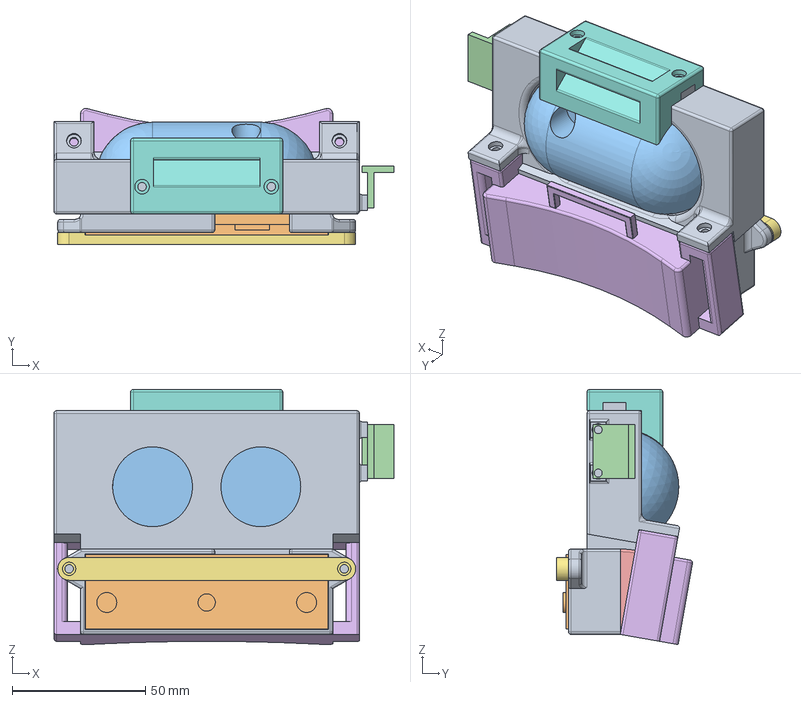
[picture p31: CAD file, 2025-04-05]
stls/Headset/HeadsetAssembly/HeadsetAssembly.step
127.8 x 51.2 x 95.9 mm
Frame
Luxonis Oak-D Lite
Speaker
Gyro Sensor
Betweener
Arc
Lip
SpeakerClamp
Offset

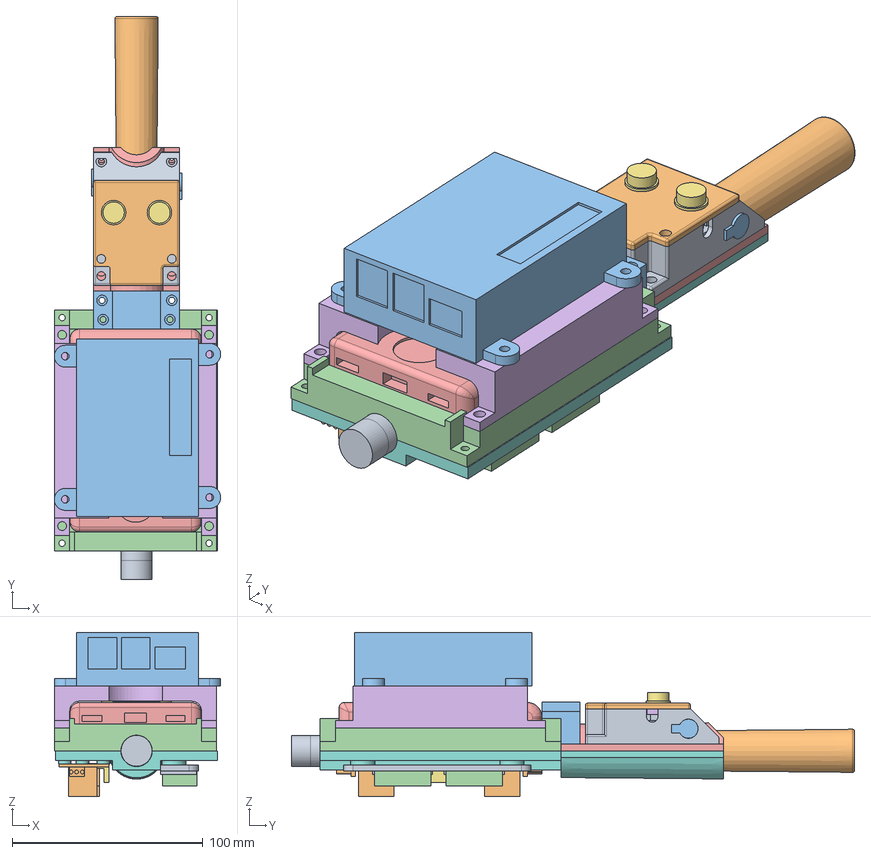
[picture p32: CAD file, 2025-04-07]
stls/SmartCane/SmartCaneAssembly/SmartCaneAssembly.step
87.2 x 295.0 x 85.9 mm
Cane Stem x 2
Cane Handle
Adapter
TopHolder
Power Bank
TopClamp
Gyro Sensor
BottomHolder
Rpi0Holder
Relay x 2
Raspberry Pi
Wago5 x 2
TopHolder_1
Button x 2
BottomHolder_1
Base
TopLayer
VibrationMotor x 2

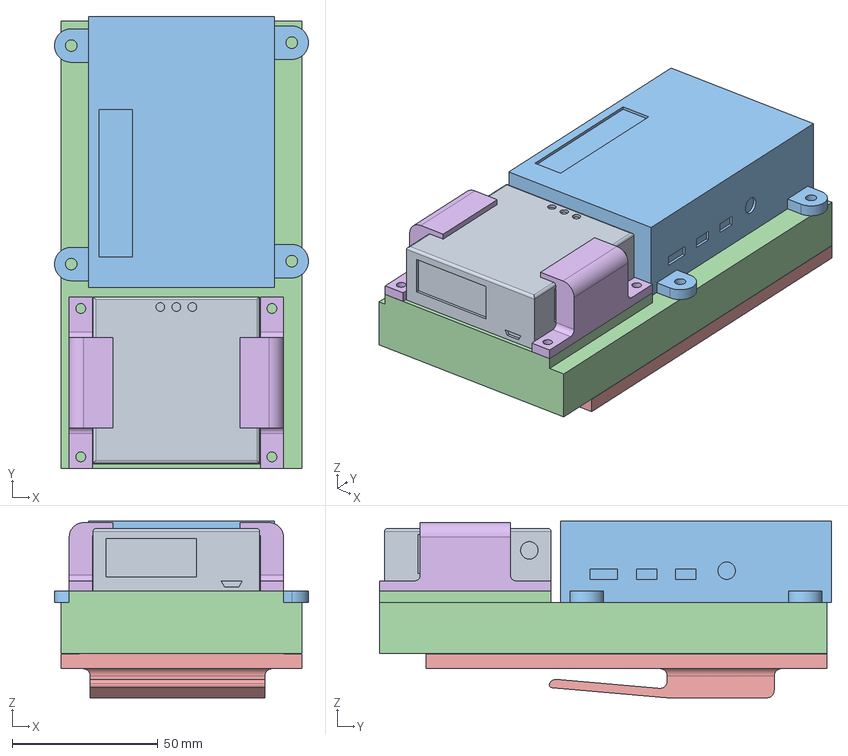
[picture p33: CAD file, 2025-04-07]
stls/SystemGateway/SystemGatewayAssembly/SystemGatewayAssembly.step
87.2 x 155.2 x 60.6 mm
Mango Router
Power Bank
Raspberry Pi
PowerBankEnclosure
PowerBankClamp
RightMangoClamp
LeftMangoClamp

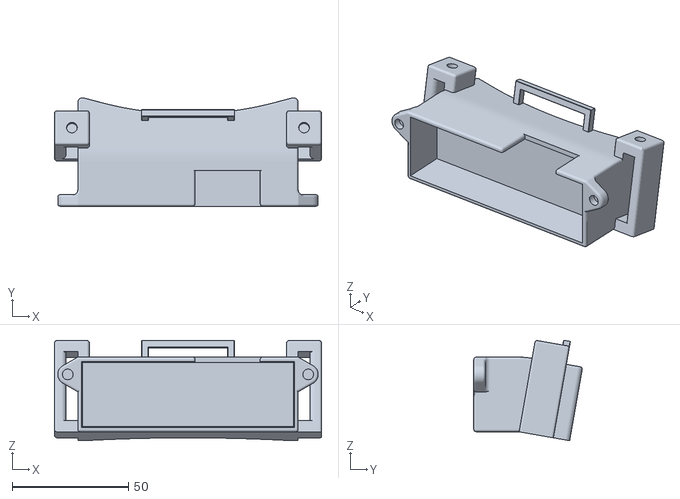
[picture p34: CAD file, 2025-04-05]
stls/Headset/HeadsetFrame/HeadsetFrameAssembly.stl
114.8 x 46.7 x 43.2

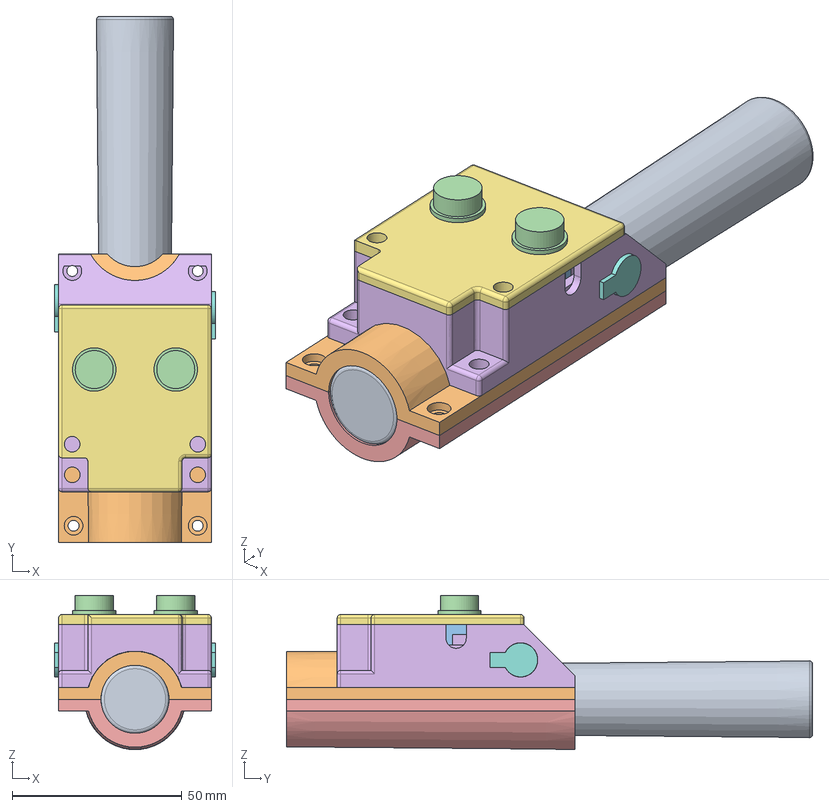
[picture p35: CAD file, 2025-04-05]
stls/SmartCane/ButtonInterface/ButtonInterfaceAssembly.step
47.4 x 155.0 x 45.4 mm
Cane Handle
TopHolder
Button x 2
BottomHolder
Base
TopLayer
VibrationMotor x 2

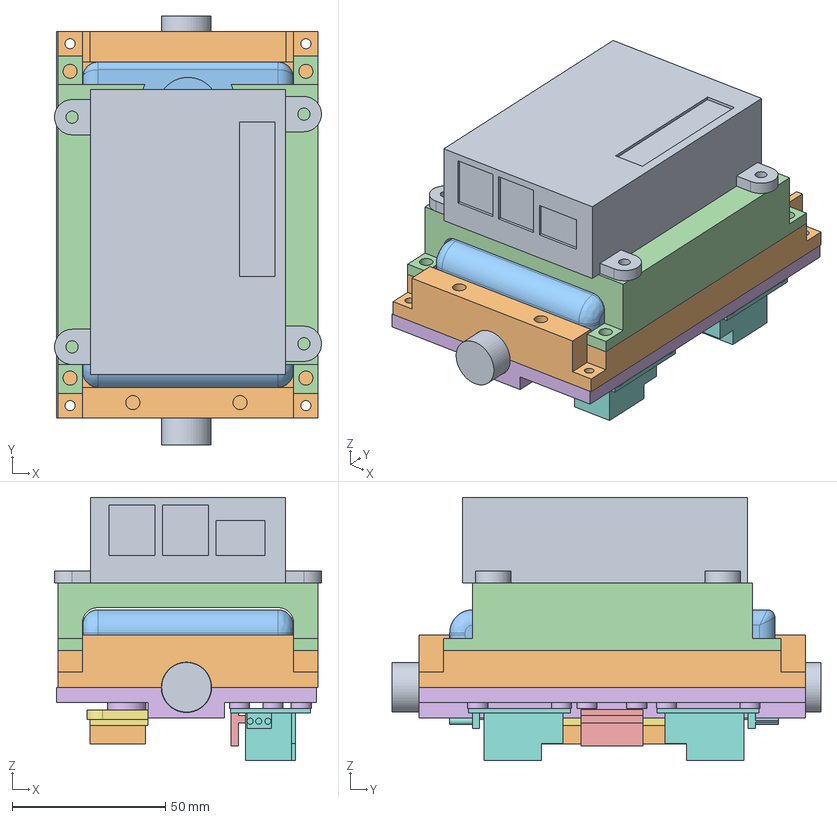
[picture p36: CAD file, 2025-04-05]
stls/SmartCane/ElectronicsHolder/ElectronicsHolderAssembly.step
87.2 x 140.0 x 85.9 mm
Cane Stem
TopHolder
Power Bank
TopClamp
Gyro Sensor
BottomHolder
Rpi0Holder
Relay x 2
Raspberry Pi
Wago5 x 2

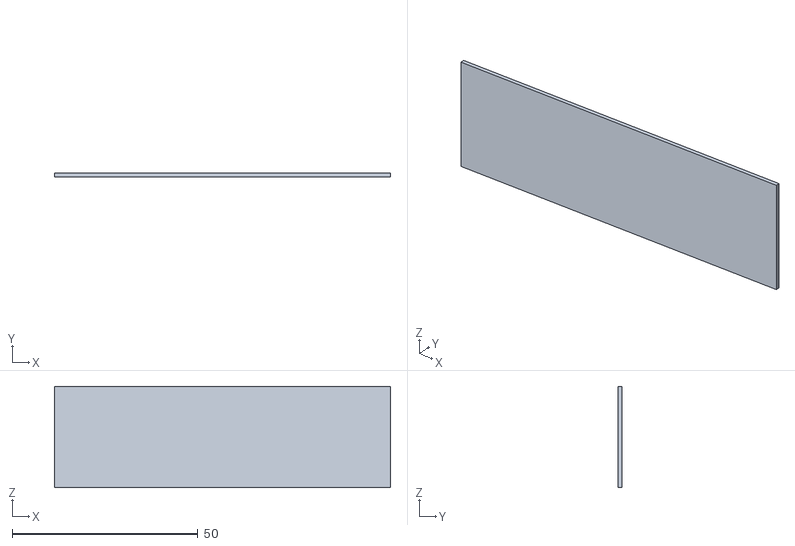
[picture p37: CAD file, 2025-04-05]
stls/Headset/CameraOffset.stl
90.4 x 1.00 x 27.2

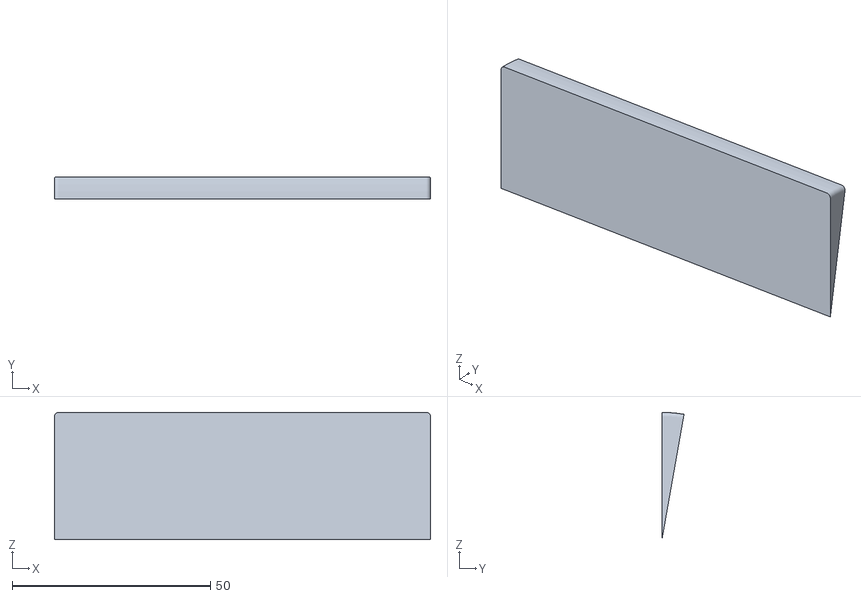
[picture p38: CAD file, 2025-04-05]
stls/Headset/HeadsetFrame/Betweener.stl
94.8 x 5.57 x 32.1

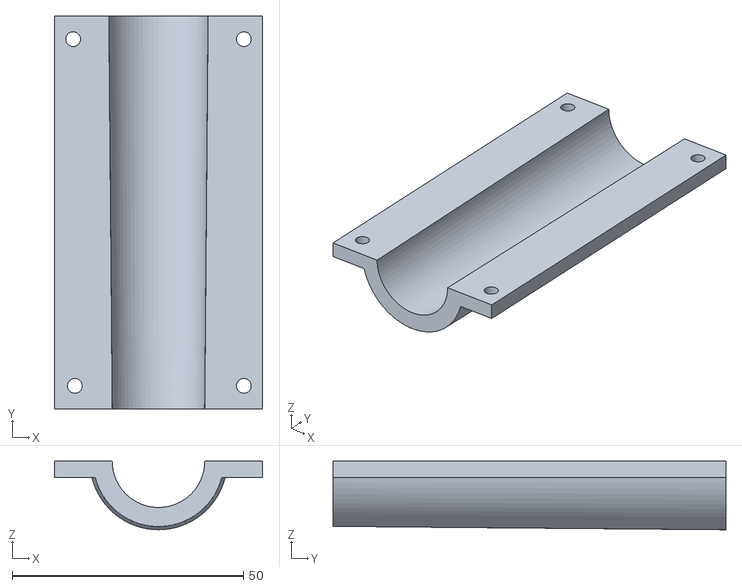
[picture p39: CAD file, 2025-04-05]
stls/SmartCane/ButtonInterface/BottomHolder.stl
45.0 x 85.0 x 14.8

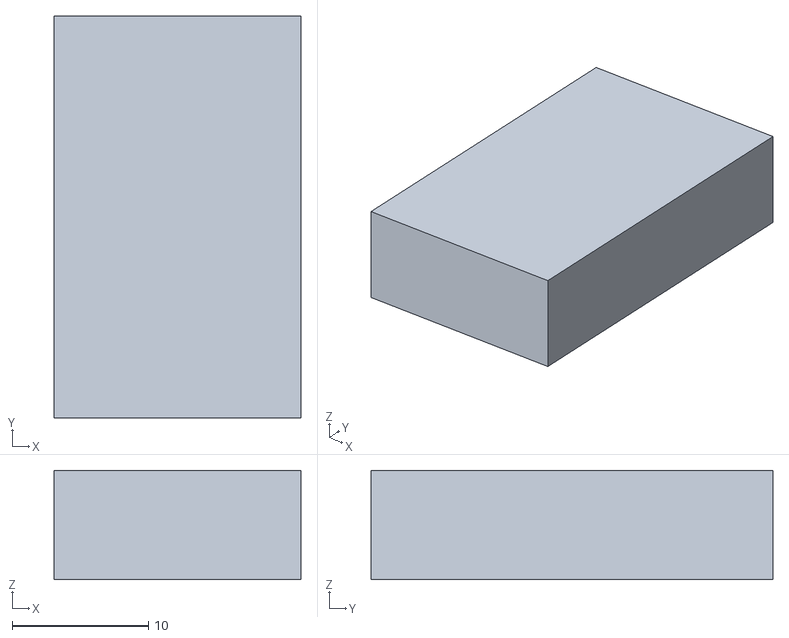
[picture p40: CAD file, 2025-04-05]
stls/SmartCane/ElectronicsHolder/WAGO.stl
18.1 x 29.5 x 8.00

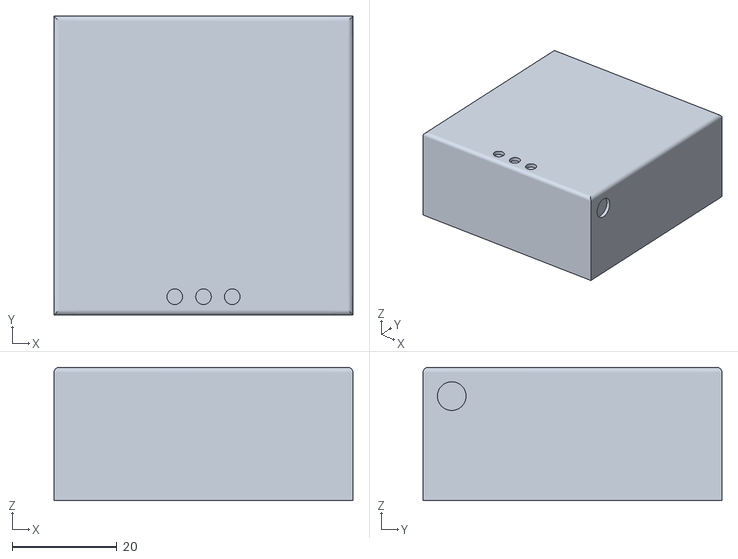
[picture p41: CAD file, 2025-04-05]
stls/SystemGateway/MangoRouter.stl
57.2 x 57.2 x 25.5

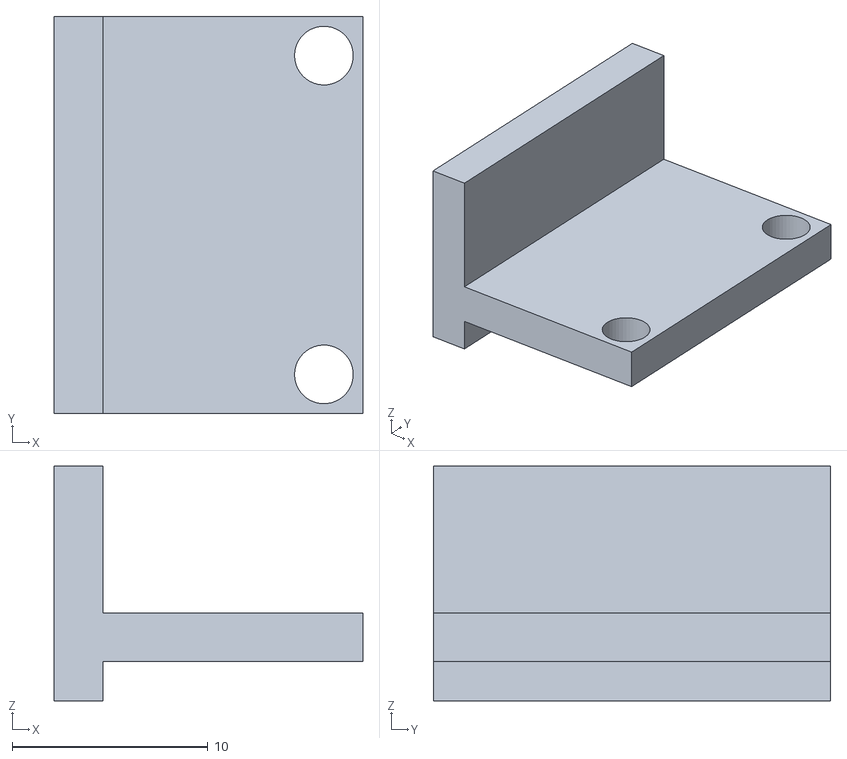
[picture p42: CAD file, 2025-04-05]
stls/Headset/GyroSensor.stl
15.8 x 20.3 x 12.0

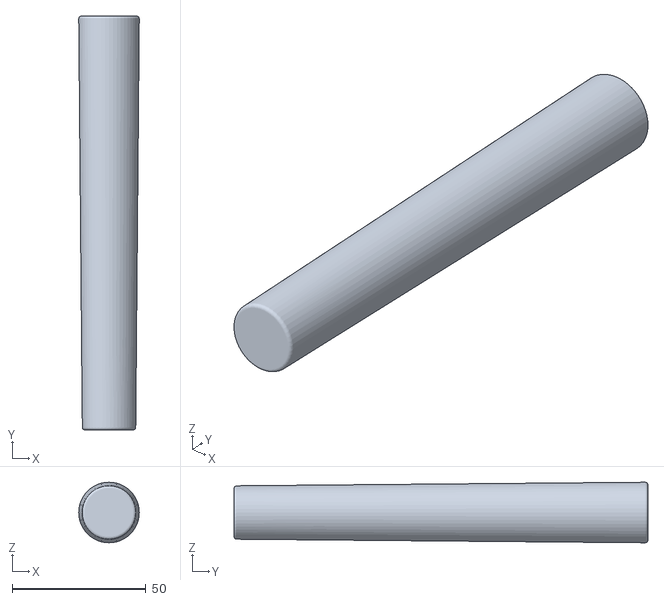
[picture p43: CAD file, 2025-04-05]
stls/SmartCane/ButtonInterface/CaneHandle.stl
22.7 x 155.0 x 22.7

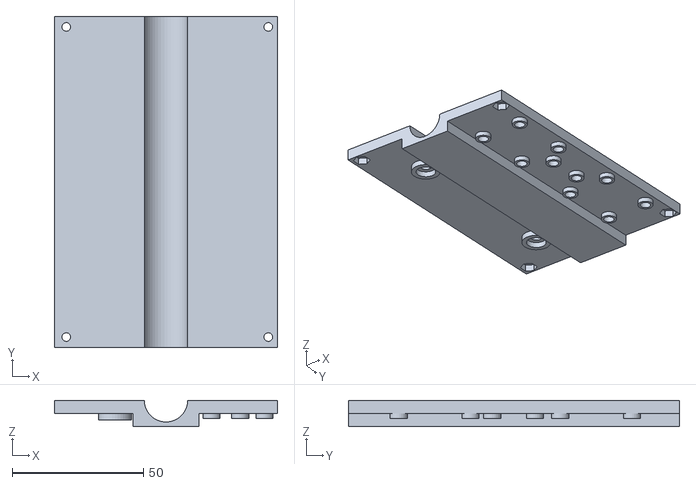
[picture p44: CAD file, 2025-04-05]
stls/SmartCane/ElectronicsHolder/BottomHolder.stl
85.0 x 126.2 x 10.0

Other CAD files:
stls/SmartCane/SmartCaneAssembly/Adapter.stl
stls/SystemGateway/PowerBankClamp.stl
stls/Headset/HeadsetFrame/Frame.stl
stls/Headset/LuxonisOakDLite.stl
stls/Headset/HeadsetAssembly/HeadsetAssembly.stl
stls/Headset/HeadsetFrame/Arc.stl
stls/Headset/Lip.stl
stls/Headset/SpeakerCage.stl
stls/Headset/SpeakerClamp.stl
stls/Headset/USBSpeaker.stl
stls/SmartCane/ButtonInterface/Base.stl
stls/SmartCane/ButtonInterface/Button.stl
stls/SmartCane/ButtonInterface/ButtonInterfaceAssembly.stl
stls/SmartCane/ButtonInterface/TopHolder.stl
stls/SmartCane/ButtonInterface/TopLayer.stl
stls/SmartCane/ButtonInterface/VibrationMotor.stl
stls/SmartCane/ElectronicsHolder/CaneStem.stl
stls/SmartCane/ElectronicsHolder/ElectronicsHolderAssembly.stl
stls/SmartCane/ElectronicsHolder/PowerBank.stl
stls/SmartCane/ElectronicsHolder/RaspberryPi.stl
stls/SmartCane/ElectronicsHolder/Relay.stl
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

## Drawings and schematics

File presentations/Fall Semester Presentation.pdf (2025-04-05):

## FALL 2024

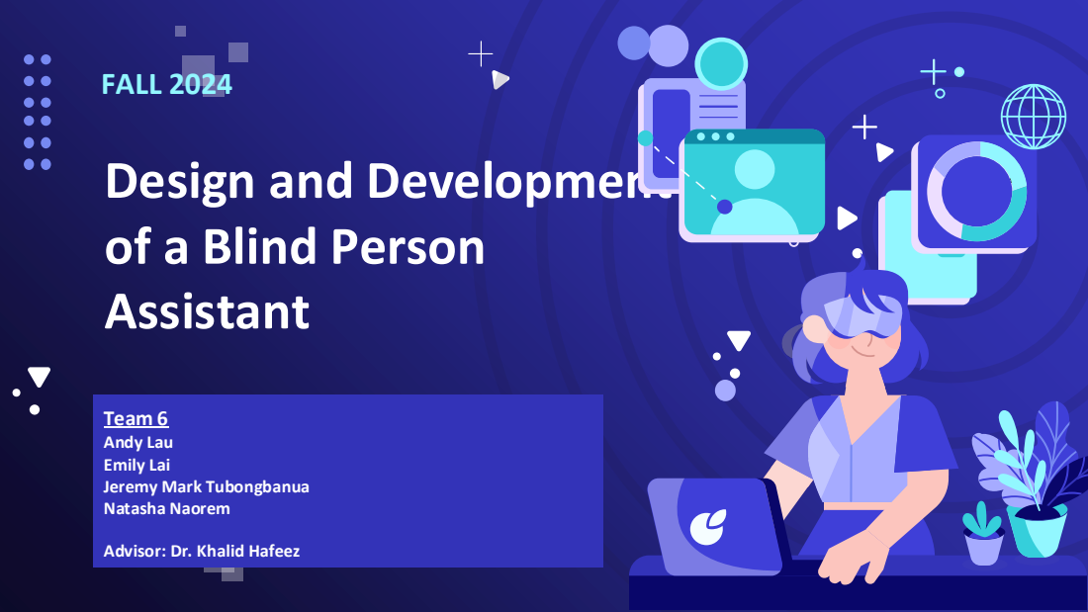
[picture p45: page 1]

Design and Development
of a Blind Person
Assistant

Team 6
Andy Lau
Emily Lai
Jeremy Mark Tubongbanua
Natasha Naorem

Advisor: Dr. Khalid Hafeez

# Problem Statement

Major Concerns of Independent Navigation

Self direction to detect
surroundings and
decide where to go

Reasonable travel time

# Existing Solutions

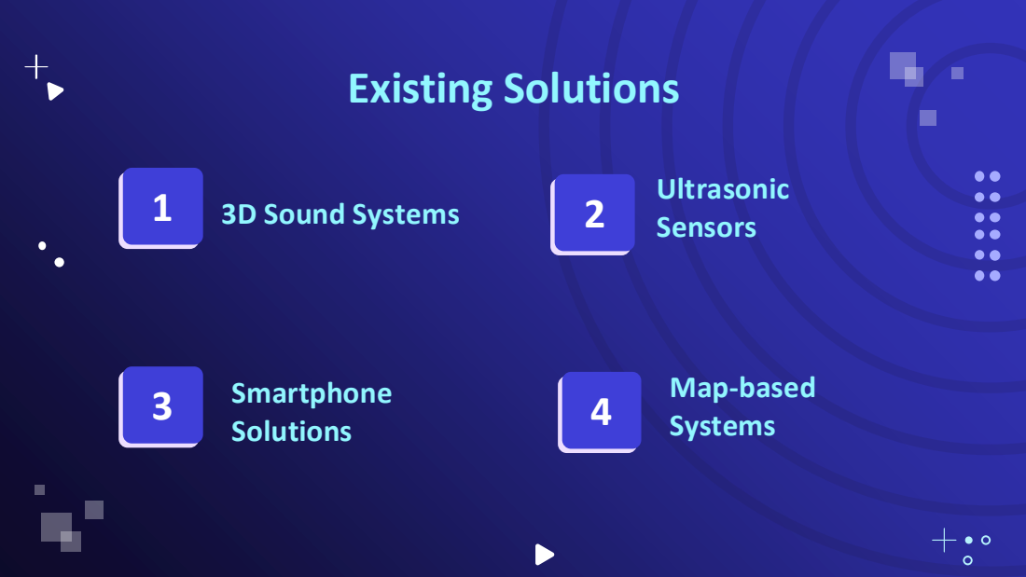
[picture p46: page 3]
Ultrasonic Sensors; 3D Sound Systems; Map-based Systems; Smartphone Solutions

# Survey Conclusion

Compared to outdoor solutions, there is a gap in the market for
development of suitable indoor orientation/ navigation systems.

# Problem Statement

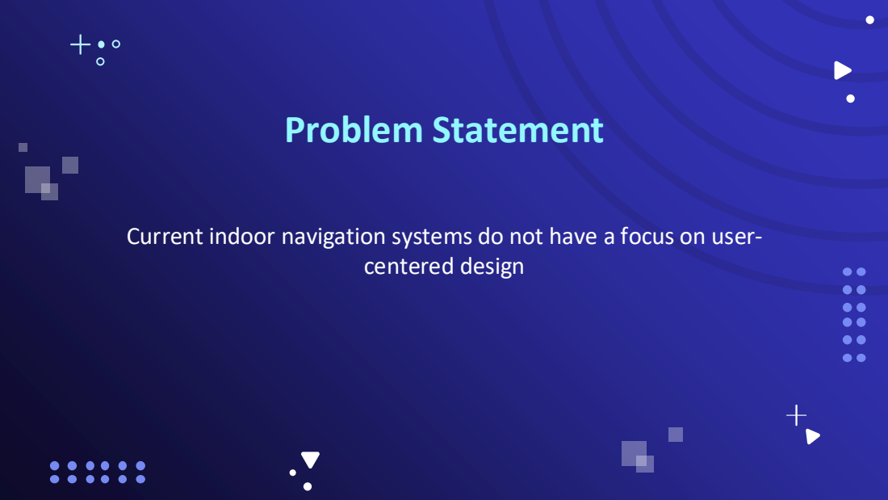
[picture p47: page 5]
centered design

Current indoor navigation systems do not have a focus on user-

# Current Solution

Orientation & Navigation
Mobile Applications
- Be My Eyes
- Google Maps
- Lazarillo
- Voice Vista

# White Cane

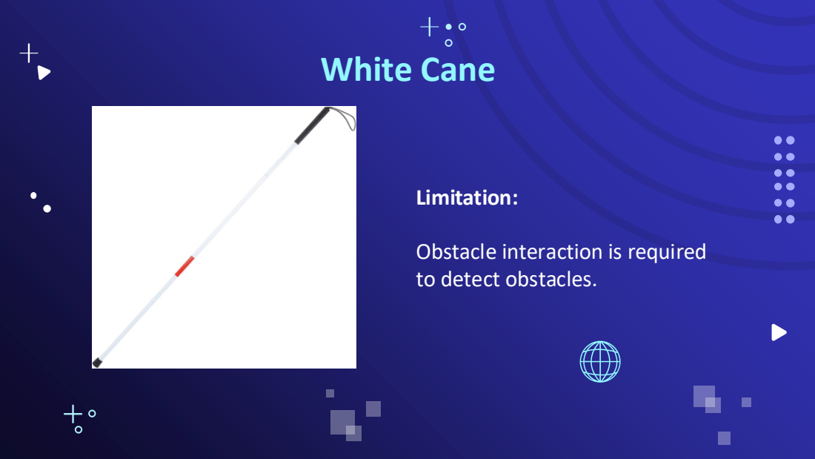
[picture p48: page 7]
Limitation:

Obstacle interaction is required
to detect obstacles.

# Guide Dog

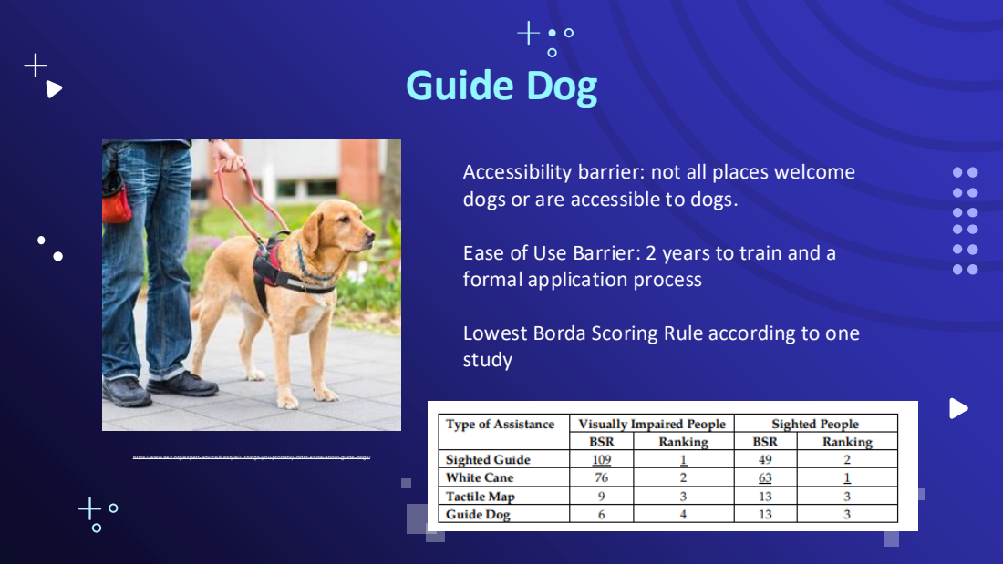
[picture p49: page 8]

Accessibility barrier: not all places welcome
dogs or are accessible to dogs.

Ease of Use Barrier: 2 years to train and a
formal application process

Lowest Borda Scoring Rule according to one
study

https://www.akc.org/expert-advice/lif estyle/7-t hings-you-probably-didnt-know-about-guide-dogs/ (https://www.akc.org/expert-advice/lifestyle/7-things-you-probably-didnt-know-about-guide-dogs/)

# Sighted Guide

# Mobile Apps

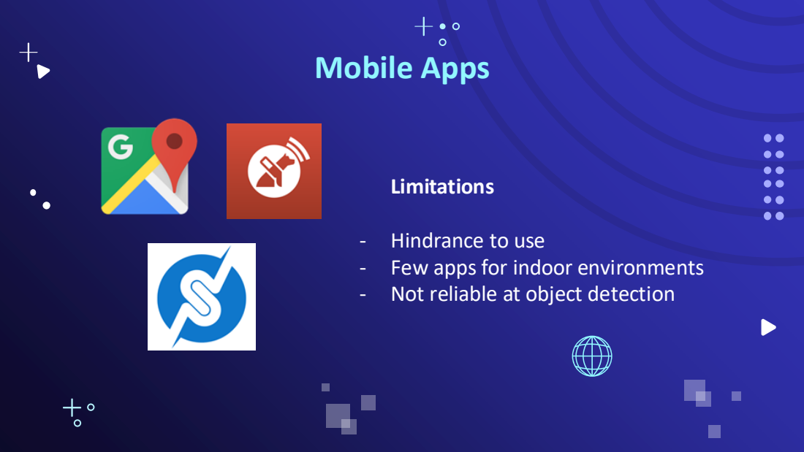
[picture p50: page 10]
Limitations

- Hindrance to use
- Few apps for indoor environments
- Not reliable at object detection

# Google Maps

“Google Maps” by Google

● “Detailed voice guidance” →
already includes solutions for the
visually impaired
● Gives directions out loud
● Dynamically changes to known
obstacles; such as construction
● Only good for broad Safety and
Orientation

## Stakeholder Discussion: Low Vision Student on Campus

Limitation: Disruptive Navigation

Simultaneous use of a white cane
and mobile phone

# Project Objectives

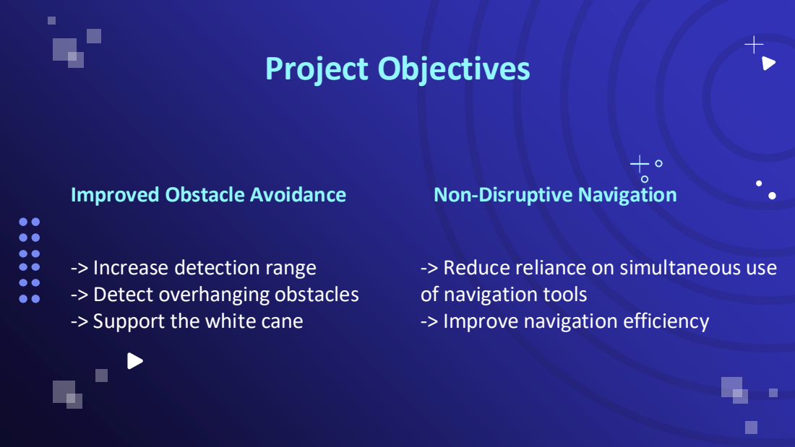
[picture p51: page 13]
Improved Obstacle Avoidance; Non-Disruptive Navigation

-> Increase detection range
-> Detect overhanging obstacles
-> Support the white cane

-> Reduce reliance on simultaneous use
of navigation tools
-> Improve navigation efficiency

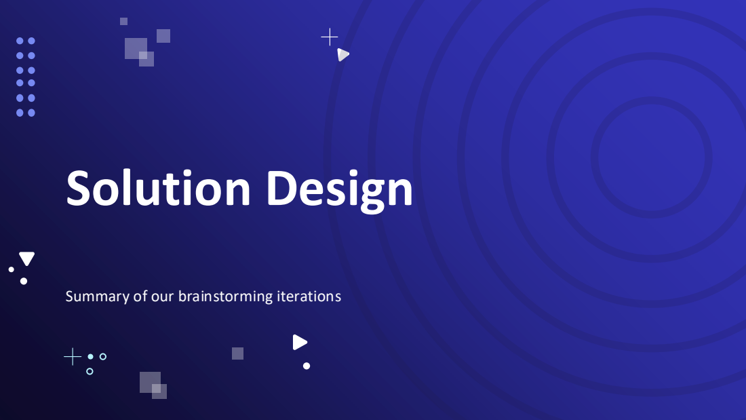
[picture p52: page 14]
Solution Design

Summary of our brainstorming iterations

# Brainstorming Process

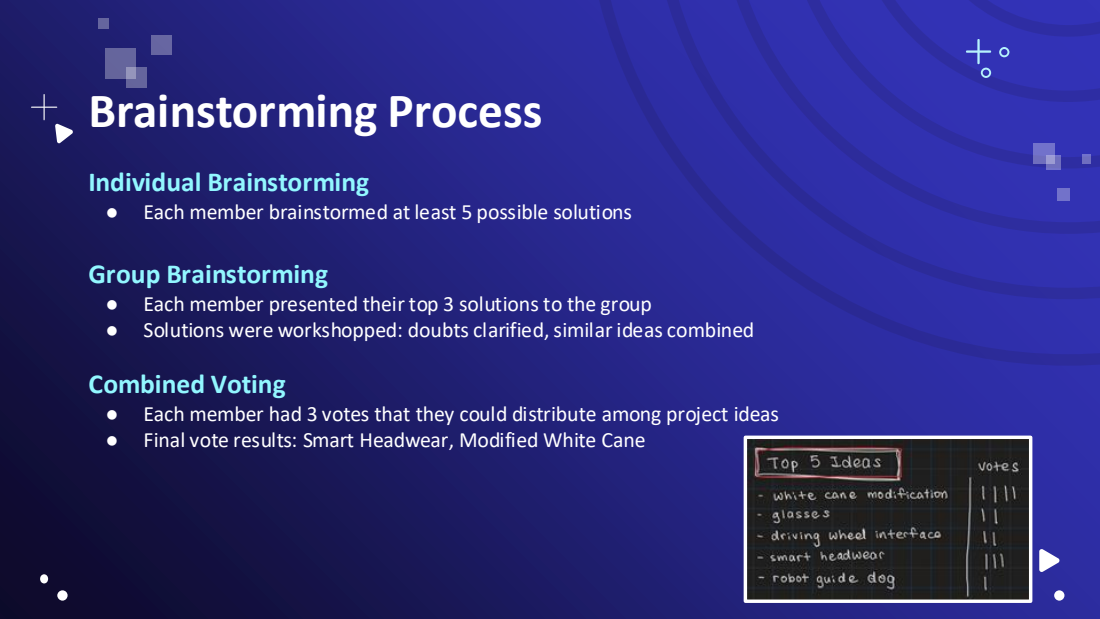
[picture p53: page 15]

Individual Brainstorming
● Each member brainstormed at least 5 possible solutions

Group Brainstorming
● Each member presented their top 3 solutions to the group
● Solutions were workshopped: doubts clarified, similar ideas combined
Combined Voting
● Each member had 3 votes that they could distribute among project ideas
● Final vote results: Smart Headwear, Modified White Cane

# Brainstorming Session 1

Smart Headwear
● Main considerations:
○ Wearability and comfort: weight, texture
○ Interaction methods: speech, buttons, etc.
○ Which elements should be included on the headwear
(Raspberry Pi, speaker, battery)

● Inspiration: Meta-Ray Ban Smart Glasses

# Brainstorming Session 2

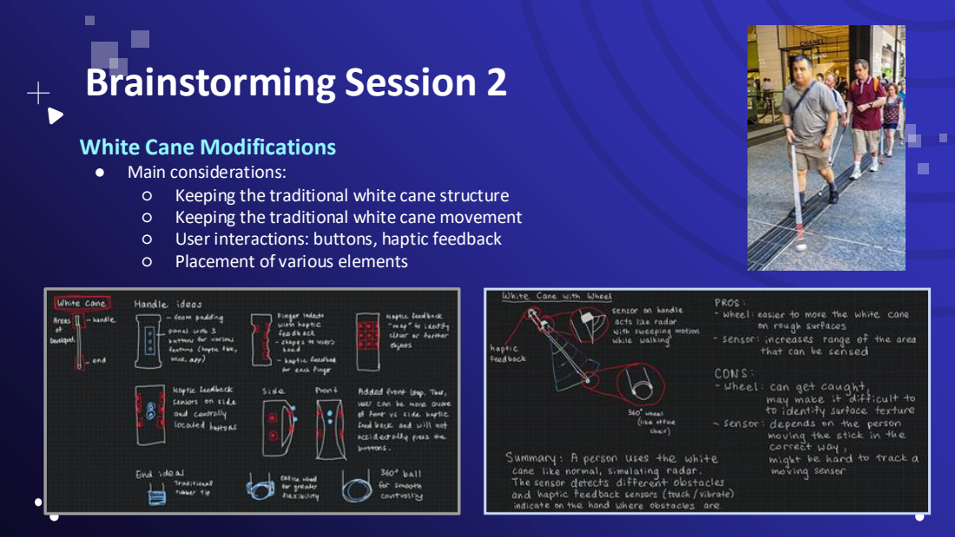
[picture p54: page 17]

White Cane Modifications
● Main considerations:
○ Keeping the traditional white cane structure
○ Keeping the traditional white cane movement
○ User interactions: buttons, haptic feedback
○ Placement of various elements

# Prototype

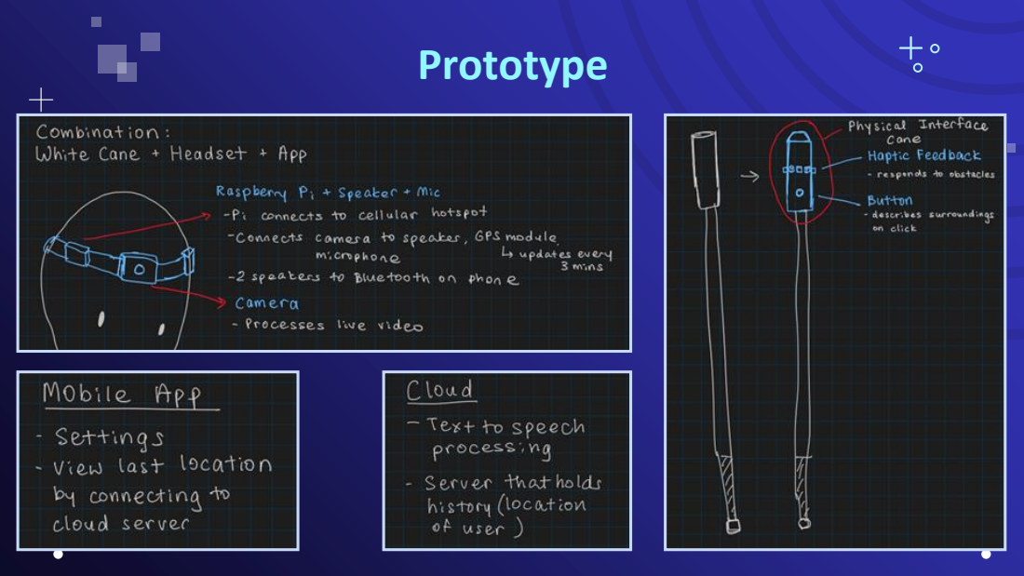
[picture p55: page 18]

The architecture of our solution

# Overall Architecture

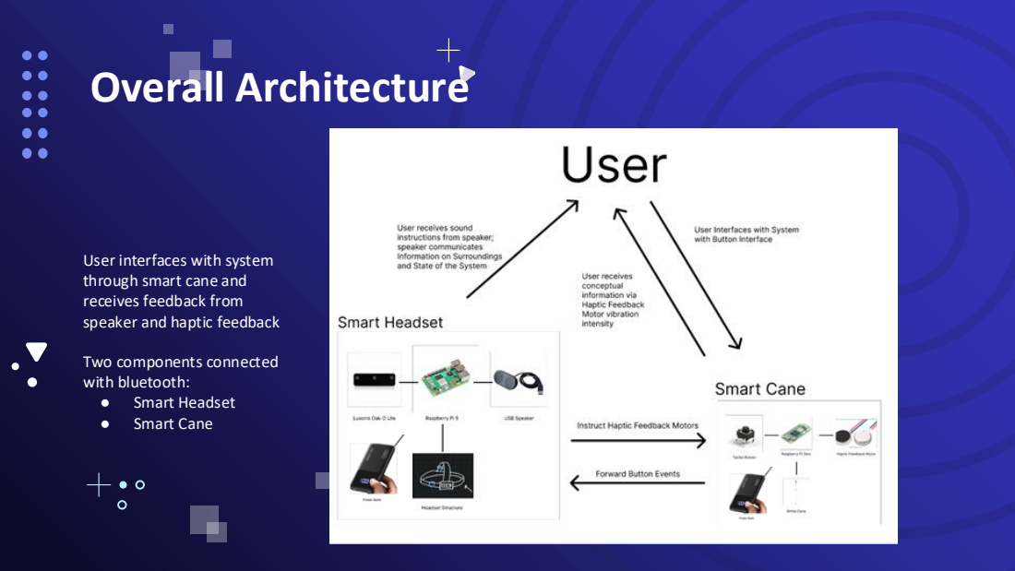
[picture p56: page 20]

User interfaces with system
through smart cane and
receives feedback from
speaker and haptic feedback

Two components connected
with bluetooth:
● Smart Headset
● Smart Cane

# Headset Architecture


● Raspberry Pi powered by power
bank
● Luxonis Oak-D Lite Depth AI Camera
transmits object depth data and
object detection and classification
data to Raspberry Pi.
○ A model is trained specifically
for our use case- to detect
certain indoor objects

● Raspberry Pi controls speaker via
USB

# White Cane Architecture


● Raspberry Pi Zero acts as a
secondary to the Raspberry Pi 5
connected to the camera and
USB speaker. It is “dumb” in
that it will only forward button
events and receive instructions
● Haptic Feedback Motors - DC
3.3V motors
● Tactile Buttons - simple
electrical switches
● Power Bank - for powering the
system

# What a Hero Use Case Looks Like

The camera detects an object

# What a Hero Use Case Looks Like


The user presses the “narrate” button
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

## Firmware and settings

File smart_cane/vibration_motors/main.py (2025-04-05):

import RPi.GPIO as GPIO
import paho.mqtt.client as mqtt
import json
import time
from time import sleep
import threading

MQTT_BROKER_RECEIVE = "192.168.2.220"
MQTT_BROKER_RESPONSE = "0.0.0.0"
MQTT_PORT = 1883
MQTT_TOPIC_RECEIVE = "pi4/vibration_motor_controller"
MQTT_TOPIC_RESPONSE = "pi2/vibration_motor_response"

LEFT_MOTOR_PIN = 22
RIGHT_MOTOR_PIN = 17

MESSAGE_TIMEOUT_SECONDS = 2000

GPIO.setmode(GPIO.BCM)
GPIO.setup(LEFT_MOTOR_PIN, GPIO.OUT)
GPIO.setup(RIGHT_MOTOR_PIN, GPIO.OUT)

GPIO.output(LEFT_MOTOR_PIN, GPIO.LOW)
GPIO.output(RIGHT_MOTOR_PIN, GPIO.LOW)

left_timer = None
right_timer = None
current_command_id = None

client_receive = mqtt.Client(mqtt.CallbackAPIVersion.VERSION2)
client_response = mqtt.Client(mqtt.CallbackAPIVersion.VERSION2)

def turn_on_left_motor():
    GPIO.output(LEFT_MOTOR_PIN, GPIO.HIGH)
    print("Left motor ON")
    return time.time()

def turn_on_right_motor():
    GPIO.output(RIGHT_MOTOR_PIN, GPIO.HIGH)
    print("Right motor ON")
    return time.time()

def turn_off_left_motor():
    GPIO.output(LEFT_MOTOR_PIN, GPIO.LOW)
    print("Left motor OFF")
    
def turn_off_right_motor():
    GPIO.output(RIGHT_MOTOR_PIN, GPIO.LOW)
    print("Right motor OFF")

def send_processing_status(message_id, left_motor_time=None, right_motor_time=None):
    response = {
        "id": message_id,
        "status": "processing"
    }
    
    if left_motor_time is not None:
        response["left_motor_trigger_time"] = left_motor_time
    
    if right_motor_time is not None:
        response["right_motor_trigger_time"] = right_motor_time
        
    response_json = json.dumps(response)
    client_response.publish(MQTT_TOPIC_RESPONSE, response_json)
    print(f"Published processing status: {response_json}")

def send_timeout_message(message_id, time_diff):
    response = {
        "id": message_id,
        "status": "timeout",
        "time_diff": time_diff,
        "threshold": MESSAGE_TIMEOUT_SECONDS
    }
    
    response_json = json.dumps(response)
    client_response.publish(MQTT_TOPIC_RESPONSE, response_json)
    print(f"Published timeout status: {response_json}")

def on_connect(client, userdata, flags, rc, properties=None):
    print(f"Connected with result code {rc}")
    client.subscribe(MQTT_TOPIC_RECEIVE)
    print(f"Subscribed to {MQTT_TOPIC_RECEIVE}")

def on_message(client, userdata, msg):
    global left_timer, right_timer, current_command_id
    
    try:
        payload = json.loads(msg.payload.decode())
        print(f"Received message: {payload}")
        
        message_id = payload.get('message_id', 'unknown')
        message_timestamp = payload.get('timestamp', 0)
        current_time = time.time()
        
        # Check if message is too old
        if message_timestamp and current_time - message_timestamp > MESSAGE_TIMEOUT_SECONDS:
            time_diff = current_time - message_timestamp
            print(f"Message too late: {time_diff} seconds (threshold: {MESSAGE_TIMEOUT_SECONDS} seconds)")
            # Send timeout message to MQTT response topic
            send_timeout_message(message_id, time_diff)
            return
        
        # Set this as the current command
        current_command_id = message_id
        
        # Cancel any active timers
        if left_timer is not None:
            left_timer.cancel()
            left_timer = None
        
        if right_timer is not None:
            right_timer.cancel()
            right_timer = None
        
        # Ensure motors are off before starting new command
        turn_off_left_motor()
        turn_off_right_motor()
        
        left_duration = float(payload.get('left_duration', 0))
        right_duration = float(payload.get('right_duration', 0))
        
        left_motor_time = None
        right_motor_time = None
        
        if left_duration > 0:
            print(f"Left motor ON for {left_duration} seconds")
            left_motor_time = turn_on_left_motor()
            
            left_timer = threading.Timer(left_duration, turn_off_left_motor)
            left_timer.start()
        
        if right_duration > 0:
            print(f"Right motor ON for {right_duration} seconds")
            right_motor_time = turn_on_right_motor()
            
            right_timer = threading.Timer(right_duration, turn_off_right_motor)
            right_timer.start()
        
        # Send the processing status once motors are activated
        send_processing_status(message_id, left_motor_time, right_motor_time)
        
        # Clear current command if motors weren't activated
        if max(left_duration, right_duration) <= 0:
            current_command_id = None
        
    except json.JSONDecodeError:
        print("Invalid JSON payload")
    except Exception as e:
        print(f"Error processing message: {e}")

def cleanup():
    turn_off_left_motor()
    turn_off_right_motor()
    GPIO.cleanup()
    print("GPIO cleaned up")
    
    if left_timer is not None:
        left_timer.cancel()
    if right_timer is not None:
        right_timer.cancel()

def setup_mqtt_clients():
    client_receive.on_connect = on_connect
    client_receive.on_message = on_message
    
    print(f"Connecting response client to MQTT broker at {MQTT_BROKER_RESPONSE}:{MQTT_PORT}")
    try:
        client_response.connect(MQTT_BROKER_RESPONSE, MQTT_PORT, 60)
        client_response.loop_start()
        print("Response client connected successfully")
    except Exception as e:
        print(f"Failed to connect response client: {e}")
        return False
    
    print(f"Connecting receive client to MQTT broker at {MQTT_BROKER_RECEIVE}:{MQTT_PORT}")
    try:
        client_receive.connect(MQTT_BROKER_RECEIVE, MQTT_PORT, 60)
        print("Receive client connected successfully")
        return True
    except Exception as e:
        print(f"Failed to connect receive client: {e}")
        client_response.loop_stop()
        return False

try:
    if setup_mqtt_clients():
        print("Starting MQTT loop...")
        turn_on_left_motor()
        turn_on_right_motor()
        sleep(0.1)
        turn_off_left_motor()
        turn_off_right_motor()
        sleep(0.3)
        turn_on_left_motor()
        turn_on_right_motor()
        sleep(0.1)
        turn_off_left_motor()
        turn_off_right_motor()
        client_receive.loop_forever()
        # vibrate for 0.5 seconds for both
    else:
        print("Failed to set up MQTT clients. Exiting.")
    
except KeyboardInterrupt:
    print("Program terminated by user")
except Exception as e:
    print(f"Unexpected error: {e}")
finally:
    client_response.loop_stop()
    cleanup()

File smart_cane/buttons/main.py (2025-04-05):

import RPi.GPIO as GPIO
import time
import json
import paho.mqtt.client as mqtt

MQTT_BROKER = "0.0.0.0"
MQTT_PORT = 1883
MQTT_TOPIC = "pi2/button_state"
HEALTH_CHECK_INTERVAL = 5  # seconds

BUTTON_PIN_1 = 16 # right button
BUTTON_PIN_2 = 26 # left button

def setup_gpio():
    """
    Initialize GPIO pins for button input with pull-up resistors.
    """
    GPIO.setmode(GPIO.BCM)
    GPIO.setup(BUTTON_PIN_1, GPIO.IN, pull_up_down=GPIO.PUD_UP)
    GPIO.setup(BUTTON_PIN_2, GPIO.IN, pull_up_down=GPIO.PUD_UP)

def setup_mqtt():
    """
    Initialize and connect to the MQTT broker.
    """
    client = mqtt.Client(mqtt.CallbackAPIVersion.VERSION2)
    client.connect(MQTT_BROKER, MQTT_PORT, 60)
    client.loop_start()
    return client

def read_button_states():
    """
    Read the current state of both buttons.
    
    Returns:
        tuple: (button1_pressed, button2_pressed)
    """
    state_button1 = GPIO.input(BUTTON_PIN_1)
    state_button2 = GPIO.input(BUTTON_PIN_2)
    
    button1_pressed = state_button1 == GPIO.LOW
    button2_pressed = state_button2 == GPIO.LOW
    
    return button1_pressed, button2_pressed

def publish_button_states(client, button1_pressed, button2_pressed):
    """
    Publish button states to the MQTT topic.
    
    Args:
        client: MQTT client instance
        button1_pressed: Boolean indicating if button 1 is pressed
        button2_pressed: Boolean indicating if button 2 is pressed
    """
    payload = {
        "button1": button1_pressed,
        "button2": button2_pressed,
        "timestamp": time.time()
    }
    
    message = json.dumps(payload)
    client.publish(MQTT_TOPIC, message)
    return payload

def print_health_check():
    """
    Print a health check message with current timestamp.
    """
    current_time = time.strftime("%Y-%m-%d %H:%M:%S", time.localtime())
    print(f"HEALTH CHECK: {current_time} - Button monitor running")

def main():
    """
    Main function to run the button state monitoring and MQTT publishing.
    """
    setup_gpio()
    mqtt_client = setup_mqtt()
    
    prev_button1_state = False
    prev_button2_state = False
    last_health_check = time.time()
    
    try:
        while True:
            current_time = time.time()
            
            # Health check every HEALTH_CHECK_INTERVAL seconds
            if current_time - last_health_check >= HEALTH_CHECK_INTERVAL:
                print_health_check()
                last_health_check = current_time
            
            button1_pressed, button2_pressed = read_button_states()
            
            if button1_pressed != prev_button1_state or button2_pressed != prev_button2_state:
                payload = publish_button_states(mqtt_client, button1_pressed, button2_pressed)
                print(f"Published: {payload}")
                
                prev_button1_state = button1_pressed
                prev_button2_state = button2_pressed
            
            time.sleep(0.1)
            
    except KeyboardInterrupt:
        print("Exiting program")
    finally:
        mqtt_client.loop_stop()
        GPIO.cleanup()

if __name__ == "__main__":
    main()

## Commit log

2025-01-13 feat: rpi2 working camera stream
2025-02-11 feat: gyro code
2025-03-03 feat: working vibration motor controller
2025-04-05 readme and stls
    [Adapter.stl, Arc.stl, Base.stl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]
2025-04-07 feat: better smartcane assembly stls
    [SmartCaneAssembly.step, SmartCaneAssembly.stl]
2025-04-07 feat: new assemblies
    [SmartCaneAssembly.step, SmartCaneAssembly.stl, SystemGatewayAssembly.step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]
